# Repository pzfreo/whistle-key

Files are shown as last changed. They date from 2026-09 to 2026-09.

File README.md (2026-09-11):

# Burke whistle key attachment

A parametric build123d attachment for a brass high-D Burke whistle. The current
prototype extends the working single key to holes **4, 5 and 6**, with three
independent curved keys and springs. The latest trial uses **35° opening** and
**2 mm EVA liners glued straight to the keys**, with no separate TPU carrier;
see the [prototype and cutting-guide instructions](docs/eva-liner-prototype.md).

See the [three-key prototype](docs/three-key-prototype.md),
[assembly STEP](exports/three-key/assembly-open.step), and
[P1S PETG print project](exports/three-key/whistle-three-key-P1S.3mf), which is
a single all-PETG plate holding everything needed. A
[closed-position assembly STEP](exports/three-key/assembly-closed.step) shows
the pads seated on the whistle. Two 3 mm spring variants are also built:
[3 x 6 mm at 35 degrees](exports/three-key-3mm-spring/) and
[3 x 5 mm at 30 degrees](exports/three-key-3mm-short-spring/); see the
[three-key prototype notes](docs/three-key-prototype.md) for the trade. The new source is [scripts/three_key.py](scripts/three_key.py).

The earlier single-key prototype is retained below for reference.

Start with the [design brief](docs/design-brief.md) for player needs, agreed
hardware, provisional dimensions, manufacturing decisions and trial criteria.
The [acceptance tests](docs/acceptance-tests.md) define engineering assertions
and the usability requirements that need physical trials.

## Single-key print projects

The [all-PETG dry-fit 3MF](exports/single-key/whistle-key-P1S-dry-fit-PETG.3mf)
contains all six pieces on one plate for the P1S, including a rigid pad.
See the [printing notes](docs/printing.md) for orientations, settings and the
separate PETG/TPU version. Open as a project and slice in Bambu Studio.

## Single-key prototype

Edit the parameter block in [scripts/single_key.py](scripts/single_key.py).
Regenerate through the build123d MCP `execute_file` tool, then validate and
export the changed parts. Geometry uses millimetres.

- PETG frame, lever and two identical clamp caps; separate 95A TPU sealing pad.
- Fixed seats for a nominal 2 × 5 mm compression spring, assumed 2 mm solid.
- A 1 × 12 mm steel dowel, friction held in the fixed supports.
- Four M2 bolts and nuts; revised clamps sized for direct contact with brass.
- Low side hinge, curved arm around the tube, reinforced cheeks and a tested
  opening stop; glue-in pad retaining ring and small pin-fit coupon.

The [assembly STEP](exports/single-key/assembly-open.step) is for reviewing the
mechanism. Use the separate files in
[print-oriented](exports/single-key/print-oriented/) for slicing; print two
copies of `clamp_cap_print`. These files have orientations and bed placement,
but do not contain slicer settings or supports.

The [measured tube and hole 4 dimensions](docs/measurements.md) are now applied.
Hole 5 diameter and the remaining reference dimensions are still provisional.
The player confirmed the 1.0 mm pin bore. The first dry fit exposed weak
supports, an ineffective stop and finger obstruction; this curved-arm revision
addresses those findings and needs another physical trial. The player has assembled the spring and hinge and reports that the TPU makes
a reasonable seal. Grip and finger/key clearance failed that trial and are
addressed in the current revision; physical rechecking is still required. CAD validity and
sampled rigid movement checks passed; printability warnings and trial details
are recorded in the brief.

## Earlier layout study

[scripts/whistle_keys.py](scripts/whistle_keys.py), the top-level exports, and
`parameters.json` retain the earlier three-key study. They are not the active
single-key specification. `parameters.json` is an inventory, not model input.
Older concept images may predate manufacturing revisions.

## Build and test

Python 3.12 is used in CI. From the repository root:

```sh
python -m venv .venv
. .venv/bin/activate
python -m pip install -r requirements-dev.txt
python scripts/build_ci.py
python -m pytest -q
```

The headless build supplies the inspection helpers normally provided by MCP and
regenerates the active model into ignored `build/`. Tests check solid validity,
bed placement, clearances at 21 key positions, spring travel, pin fit geometry,
and STEP/STL round trips. They do not establish physical sealing or comfort.

[Build and test CAD](.github/workflows/cad.yml) runs on pushes, pull requests and
manual dispatch. Successful runs publish regenerated CAD files and a geometry
report as a downloadable `whistle-cad` artifact. Both the single-key and current
three-key prototypes are regenerated and tested.

## Titanium machining drawing

The [Draftwright drawing package](drawings/titanium/README.md) contains a
[two-sheet PDF](drawings/titanium/frame-machining-review.pdf), dimensioned DXFs,
a datum-aligned STEP and the Python regeneration script. It is for machining
quotation/review; material grade, metal pin retention and final instrument
measurements must be resolved before cutting.

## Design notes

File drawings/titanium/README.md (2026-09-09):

# Titanium frame — machining review P1

This package describes the existing three-key lower frame for a CNC machining
quotation and design-for-manufacture review. It is **not released for cutting**.
The titanium grade, metal hinge-pin retention, cutter access/internal radii,
and the player's hole 5/6 measurements remain unresolved. No supplier has been
contacted and no machining order has been placed.

The frame is a 3D milled/drilled component, not a flat laser/waterjet profile.
Its nominal envelope is **31.300 × 71.595 × 15.300 mm**. The 3.5 mm base is only
one level; raised bearings and spring housings are integral. Stock allowance
and workholding must be chosen by the machinist.

## Package

- `frame-machining-review.pdf`: combined two-sheet PDF for sharing.
- `frame-general.pdf`: orthographic/isometric views, envelope dimensions,
  proposed machining notes and release holds.
- `frame-features.pdf`: coordinate schedule, hole callout and functional sizes.
- Matching SVG and DXF files are drawing sheets, **not cutting toolpaths**.
- `frame-reference.step`: exact nominal geometry for CAM review. No titanium
  redesign or tool-radius compensation has been applied.
- `drawing-checks.json`: version/hash provenance and Draftwright diagnostics.
- `../../scripts/draw_titanium_frame.py`: reproducible Draftwright Python source.

The STEP is the committed PETG frame translated into a machining coordinate
system: X=0 is the whistle centreline, Y=0 the foot-end clamp centre and Z=0 the
flat underside. +Y points towards the mouthpiece; +Z towards the whistle.
Relative to `frame_print.step`, the translation is (0, 32.2975, 0) mm. Its shape
and volume are unchanged. Dimensions are in millimetres; do not scale a drawing.
Use the STEP for unlisted contours, with the drawing's fit notes and release
holds. Coordinate locations are nominal, not a claim that the instrument has
been measured to three decimal places.

## Manufacturing decisions to resolve

1. **Pin retention.** The 1.10 mm fixed bores were a PETG print-fit experiment.
   A machined 1.10 mm bore and 1.00 mm pin have 0.10 mm diametral clearance.
   Do not call this a press/friction fit. Agree bore limits and retention using
   the actual pins before revising the CAD. Preserve access for pin insertion.
2. **Nut pockets and internal corners.** The six 4.30 mm AF hex pockets have
   sharp nominal corners. Ordinary end milling leaves internal radii; the
   shop must propose corner relief or a suitable secondary process. Relief
   must preserve the nut-bearing flats, 1.6 mm roof and surrounding wall.
   This follows [Protolabs' CNC milling guidance](https://www.protolabs.com/services/cnc-machining/cnc-milling/design-guidelines/).
   Other sharp internal intersections also need cutter-access review; no blanket
   permission to add radii in moving-key clearances is given.
3. **Small cross holes and blind seats.** Six coaxial bearing bores run along Y.
   Three 2.4 mm spring sockets run along X and require a flat floor at full
   specified depth. A standard drill-point depth is not interchangeable with
   the 1.5 mm cylindrical spring seat. Inspect access and fixturing from both
   sides, underside and above.
4. **Whistle fit.** Three R7.15 seats share an axis. The 14.2 mm brass whistle,
   existing PETG caps and 1.2 mm nominal split gap are the starting interfaces.
   A geometric tightening allowance alone does not establish titanium clamp
   grip or acceptable pressure on the brass. Trial the metal assembly.
5. **Measurements and material.** Key 5/6 dimensions are being rechecked.
   Confirm these before fixing pedestal positions. Titanium grade and condition
   are not assumed. Tolerances and surface finish on the drawing are proposals
   for review, not measured or supplier-approved capability.

## Regeneration

Use a separate environment: the CAD project's tests use build123d 0.11.0,
whereas the inspected Draftwright version requires build123d below 0.11.

```sh
python -m venv /tmp/whistle-drawing-venv
/tmp/whistle-drawing-venv/bin/pip install -r drawings/titanium/requirements.txt
/tmp/whistle-drawing-venv/bin/python scripts/draw_titanium_frame.py
```

After changing the model, regenerate and datum-align the STEP through build123d
MCP before running the drawing script. The script reads the model parameter
block, checks the source STEP and emits the views through Draftwright. Review
both the machine-readable lint and the rendered PDFs; a clean drawing-layout
report would not release the part for manufacture.

## Drawing review and limitations

The fully automatic first pass reported dropped bore callouts and was stopped
after repeated layout retries. The refined version explicitly declares separate
bolt, spring and hinge hole groups and uses a coordinate table. This avoids
conflating the six vertical 2.4 mm bolt holes with the three horizontal 2.4 mm
blind spring sockets. It also adds a clamp section and shorter title-block text.

Visual inspection exposed two section-renderer issues in the pinned Draftwright
revision: rear-facing surfaces behind the section plane were hatched, and the
cut indicators pointed opposite the rendered +Y viewing direction. The drawing
script contains a narrowly scoped workaround: hatch only faces lying on the
specified cutting plane, and orient the indicators into the retained half.
It records hatch-face areas and excluded uncut faces for inspection. No manual
page coordinates are used to relocate views or dimension labels.

Draftwright still reports unsupported hex-pocket grammar and incomplete or
unverifiable feature provenance. Those warnings are retained in the JSON files;
the package does not claim automatic completeness. The coordinate and feature
notes supplement the views, and the STEP carries the remaining contours.
Independent assertions check actual cylindrical surfaces (counts, centres,
axes and depths), all 36 nut-pocket walls, and preservation of the original
frame geometry under translation. These are geometry checks, not validation
of metal friction fits, stiffness or manufacturing capability.

## Status update — 2026-09-09

The player has confirmed the recorded hole measurements. The measurement hold
on the archived P1 sheets is resolved. All three keys/pads now share the hole-5
size; this changes no frame geometry or hole coordinates. The P1 PDFs and trial
report are retained as issued. Material, metal pin retention and machining
intent still need resolution before a manufacturing release.

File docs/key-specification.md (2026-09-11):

# Burke whistle assistive key specification

This document is the restart specification for the three-key prototype. It
records the measured instrument, the agreed mechanical interfaces, and the
current experimental choices. It is intended to be sufficient to rebuild the
design in a new CAD session. All dimensions are millimetres unless stated
otherwise. The parametric implementation is `scripts/three_key.py`.

## Purpose and scope

The attachment adds normally-open keys to holes 4, 5 and 6 of a cylindrical
brass Burke high-D tin whistle. The keys let the player close a hole with a
deliberate press while reducing accidental muffling from a resting right-hand
index or middle finger. The key must return positively to an open stop when the
finger is released.

This is an assistive prototype, not a finished musical-instrument mechanism.
Tone, intonation, airtightness, fatigue life, spring force and comfort require
physical trials. CAD clearances are nominal and do not account for printer
tolerance, glue, foam hardness or spring-rate variation.

## Instrument datum and measured holes

Use the open foot of the whistle as axial datum zero. The whistle is cylindrical
at the attachment and has 14.2 OD. Hole positions are measured independently
from the foot; do not reconstruct them by adding adjacent gaps.

| Hole | Bottom edge | Axial diameter | Derived centre | Derived top edge |
|---|---:|---:|---:|---:|
| 3 (reference) | 100.00 | 5.80 | 102.90 | 105.80 |
| 4 | 79.15 | 5.09 | 81.695 | 84.24 |
| 5 | 62.05 | 7.80 | 65.950 | 69.85 |
| 6 | 35.30 | 7.60 | 39.100 | 42.90 |

The hole 4 transverse reading is 5.09. Transverse dimensions of holes 5 and 6
are not confirmed. Until they are measured, the model uses circular envelopes
from the axial readings as conservative clearance references, not as an
acoustic model. The direct gap checks were: hole 3 bottom to hole 4 top 15.60,
hole 4 bottom to hole 5 top 9.22, hole 5 bottom to hole 6 top 19.20, and hole 4
bottom to hole 6 top 36.30.

## Key layout

There are three identical interchangeable keys. They are intentionally sized
for the largest measured hole and are not engraved or position-specific.

- Common pad/contact diameter: 12.30.
- Key pad face outside diameter: 14.20 nominal, matching the whistle OD
  envelope. Minimum axial clearance between adjacent pads is 1.545.
- The pad face is integral with the key: a dished boss on the key underside,
  cut by a cylinder of 8.90 radius concentric with the whistle at closure
  (7.10 tube radius, less 0.20 interference, plus the 2.0 sheet).
- The glue surface is one continuous cylindrical face of 175.69, with no
  retaining ring, tab notch, step or parting line on it.
- Solid PETG above the dish: 3.80.
- The separate TPU carrier, its retaining ring and the pad locating tabs are
  superseded, as is the earlier widened carrier flare.

The key is a curved arm around the whistle, with a 4.0-wide hinge region, 3.0
thickness, 3.5 rear tail extension, and a widened 6.0 upper load path. The
upper arm has 1.0 extra radial stock and a 0.8 transition radius. A continuous
rear/tangent web fills the former weak notch. The hinge pivot axis is parallel
to the whistle axis, at X = -11.2 and Z = 0 in the local section coordinates;
the derived arm radius is 11.2. The pivot pin is 1.0 diameter.

The nominal open angle is 35°. Rotation is toward the open stop. At that stop,
the calculated pad-centre lift is 4.670 and the current uncompressed EVA
surface is about 4.163 from the reference tube. The angle was increased from
the earlier 20°/30° trials to keep the pad away from the airway. Forty degrees
was rejected for the current spring geometry because it leaves almost no
compression reserve.

## Pad and seal

The current pad system has one part: a single piece of 2.0-thick EVA sheet
glued into the dished face of the key. There is no separate carrier and no
second EVA layer. The nominal model uses 0.20 compression allowance at closure;
this is a trial assumption, not a measured foam property.
The EVA cutting guide is approximately 14.59 × 14.20 and is unrolled at the
mid-thickness radius. Trace and cut one liner first, curve it into the key's
dished face, check the edge, then glue it with a thin even layer suitable for
the actual PETG
and EVA. Do not cut a central hole in the liner.

The pad is intended to seal around each hole while leaving the hole itself
open when the key is raised. The CAD sealing-band check probes the current
face around each hole; physical leak and tone tests are mandatory. The open
pad must not intrude into the immediate airway. A changed pad outline or liner
thickness requires rerunning the sealing, airway and travel tests.

## Hinge, pin and spring

Each key has one friction-held steel dowel and one sideways compression spring.

- Pin: 1.0 × 12.0 steel dowel.
- Fixed bearing bores: 1.10 nominal diameter, with 0.25 lead-in allowance.
- Moving key bore: 1.25 nominal diameter.
- Fixed bearing crown radius: 3.0; minimum continuous collar wall: 0.90.
- Bearing ears are 3.2 axial thickness, leaving about 0.5 pin projection at
  each end. Pin insertion is from the foot end, in order 4, then 5, then 6.
- Spring: nominal 2.0 OD × 5.0 free length compression coil. Solid height is
  assumed 2.0; wire is nominally 0.3. The spring rate is unknown and must not
  be inferred from these dimensions.
- Closed spring seat spacing: 2.80. Current open spacing: about 4.624, leaving
  about 0.376 nominal compression at 35°.
- Spring socket diameter: 2.4, socket depth 1.5. Moving peg is 1.2 at its
  base, tapering to 1.0 at a 1.5-long tip.
- Spring seats are at Z = 3.1 in the current design. An 0.8 bevel at the upper
  rear holder corner clears the key's pad boss during travel.

The ordered 3.0 × 5.0 springs are not part of this revision. If a spring is
changed, check both solid-height margin and positive return before changing
the opening angle.

## Frame, clamps and fasteners

The frame is a PETG printed structure with three split clamps, three reinforced
hinge pedestals, a continuous low spine and an opposite-side 5.0-wide return
rail. Clamp centres are 28.10, 52.475 and 92.695 from the foot. The middle
clamp sits between holes 5 and 6. End clamp bands are 4.0 wide; bolt supports
are 6.0 wide. The nominal clamp inner radius is 7.15 (14.3 diameter seat for
the bare 14.2 whistle), with 0.05 radial clearance and a 1.2 split gap.

Use the matching printed caps. The frame and caps have underside hex pockets:
4.30 across flats, 1.90 deep, for nominal M2 nuts 4.00 across flats × 1.60
thick. Pocket clearance and actual nut dimensions need a physical fit check.
M2 bolt head envelope is 2.4 diameter × 2.0 high. The user's M2 bolts and nuts
are the intended hardware; exact bolt length remains to be confirmed.

The clamp faces must grip the bare whistle without a liner. A CAD closure check
shows the seat contacts before the faces bottom, but it does not establish grip
force. Tighten only enough to prevent movement and inspect the brass for marks.
The rail, clamp and hinge geometry must preserve finger access, especially over
the hole above the keyed hole.

## Materials and printing

- Frame, keys, caps and EVA cutting guide: PETG. Every printed part is PETG.
- Pads: 2.0 EVA foam sheet, cut from the supplied guide; not printed.
- Pins: friction-fit 1.0 × 12 steel dowels.
- Springs: nominal 2 × 5 compression coils.
- Adhesive: compatible with the selected PETG and EVA; thin glue layer.

Use the supplied P1S 3MF orientations. The frame and keys are printed with
their specified supports; the cutting guide is flat-base-down and
support-free. Print three identical keys. The single-plate 3MF holds the same
PETG parts as the two-plate project.

## Acceptance requirements

Automated CAD checks should verify:

- all three independent hole positions and common interchangeable geometry;
- valid closed solids and STEP/STL round trips;
- 21 sampled positions through the full 35° travel;
- key, pad, frame, tube and cap collision clearance;
- actual opening-stop contact and overtravel interception;
- open airway clearance;
- spring solid-height and preload margins, plus hinge/collar clearance;
- pin insertion path and bearing fit;
- sealing coverage around all three holes;
- pad tabs, ring notches and full pad seating;
- clamp, bolt-head and M2 nut-pocket geometry.

Physical trials remain required for print strength, pin insertion effort, spring
return, opening/closing force, clamp grip, EVA adhesion, airtight sealing,
finger clearance, fatigue and sound. Specifically compare each open note with
the unkeyed whistle; the 35° CAD clearance is not proof that the pad has no
acoustic effect.

## Restart checklist

Start from `scripts/three_key.py`, set the measured hole table and 14.2 tube
OD, then rebuild through the build123d MCP workflow. Regenerate the three-key
build and both 3MF projects, run `tests/test_three_key.py` and
`tests/test_package_3mf.py`, validate the printable parts, and inspect the
assembly STEP. Do not silently reuse older 20° or widened-carrier exports.

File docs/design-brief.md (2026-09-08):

# Burke whistle key attachment — design brief

Status: single-key development prototype, not yet fitted or played.
Updated: 7 September 2026.
Active parametric model: [`scripts/single_key.py`](../scripts/single_key.py).

## Purpose and player needs

Develop a removable key attachment for an existing brass Burke high-D tin
whistle. The player has Parkinson's disease and finds deliberate movements
against resistance easier to control than very light movements. The right index
finger, and to some extent the middle finger, can rest too close to a tone hole
and muffle notes even when that hole should be open.

The attachment should hold each affected hole positively open until the player
intentionally presses its key. The player should be able to rest a finger on the
contact without inadvertently shading the hole or partly closing the pad.
Required resistance and comfortable travel will be established by playing
trials, separately for each finger. Improvement in control is a design objective,
not a demonstrated result.

## Scope and agreed decisions

The eventual attachment covers holes 4, 5 and 6, numbered from the mouthpiece,
using three independent, normally open keys. The immediate prototype covers
only hole 4, operated by the right index finger. Validate this key before
extending the design to all three.

- Retain the existing instrument; use removable, lined split clamps.
- Use a printed supporting frame and a separate hinged finger lever.
- Use compression coil springs with fixed seats. Change resistance by replacing
  the spring, not by adding spring adjustment screws or torsion springs.
- Use a purchased 1 mm diameter × 12 mm steel dowel as the pivot. Hold it by
  friction in the fixed supports; provide running clearance in the moving key.
- Use the player's available M2 bolts and nuts for the clamp halves.
- Prototype a custom 95A TPU pad with a continuous curved sealing face.
- Print rigid parts in PETG on a Bambu Lab P1S; print the TPU separately.
- Keep dimensions in millimetres and geometry parametric in build123d.

## Mechanical layout

Two split clamps, immediately above and below hole 4, carry a short side rail.
The rail carries two pivot supports, spring seat and a fixed opening stop.
A curved lever wraps around the tube from a low side hinge, whose axis runs
parallel to the whistle at tube-centre height. Its round upper contact accepts the finger; the pad beneath closes
against the outside of the brass tube.

The spring pushes the lever open against a fixed stop. Some compression remains
at the open position to provide positive return. Deliberate finger pressure
closes the key against the spring. The TPU pad against the brass sets the closed
position; there is no separate rigid closing stop. Spring force at the finger depends on the lever
geometry as well as the unknown spring rate.

The prototype retains two clamps for mounting stability. Check that their
position leaves room for the other fingers and does not obstruct adjacent holes.
The CAD reference tube is only a lower tube segment, not a complete acoustic
model of a whistle.

## Pad and seal

The current trial pad is a separate TPU insert with a flat backing and a concave
cylindrical face matching the nominal outside of the tube, with 0.2 mm radial
interference for trial compression. The contact face is continuous across the
centre: the earlier annular lip and central relief have been removed at the
player’s request. The opposite backing is plain and flat.

A shallow retaining ring on the rigid key forms a flat-bottomed pad cup. Glue
the pad into this ring, aligning its curved face with the whistle before the
glue sets. The ring is 1.2 mm deep, with 0.8 mm walls and 0.3 mm total diametral
clearance around the pad. The TPU projects beyond the rigid rim so it contacts
the brass first. There is no central peg or recess in the pad backing.

The player will trial available 95A TPU first. Its firmness, printed texture,
seams and inaccurate alignment may cause leaks. The current dimensions are experimental; CAD validity does not prove
airtightness. Retain the option of a soft silicone sealing layer if printed TPU
cannot seal reliably at a comfortable force.

## Dimensions and assumptions

The player has supplied the [tube and hole 4 measurements](measurements.md).
Remaining unmeasured reference dimensions retain provisional high-D values.

| Item | Current value | Basis/status |
|---|---:|---|
| Tube outside diameter | 14.2 mm | Measured; cylindrical tube confirmed |
| Tube wall | 0.396875 mm | Provisional; bore derived from OD and wall |
| Hole 4 centre from open foot | 81.68 mm | Measured |
| Hole 5 / 6 centres from foot | 65.68 / 43 mm | Hole 5 derived from measured 16 mm spacing; hole 6 provisional |
| Hole 4 / 5 / 6 diameters | 5.09 / 6 / 5 mm | Hole 4 measured circular; holes 5/6 provisional |
| Single-key frame length | 26 mm | Upper clamp moved inward for finger clearance |
| Clamp width, each | 4 mm raised band; 6 mm bolt supports | Clearance revision |
| Nominal split gap | 1.2 mm | Bare-tube seat contact before bottoming checked |
| Liner allowance, radial | 0 mm | Direct brass contact; 0.05 mm radial seat clearance |
| Finger contact diameter | 11.49 mm | Widened to support retaining-ring wall |
| Pad-centre opening movement | 3.25 mm at 20° | Curved arm moves pad sideways as well as upwards; acoustic/comfort trial required |
| Pivot pin | 1 × 12 mm | User-identified steel dowel |
| Support / moving-key bore | 1.1 / 1.25 mm | Current printed-fit trial |
| M2 screw clearance | 2.4 mm | Prototype choice |
| TPU pad outside diameter | 9.59 mm | Derived from measured hole plus trial sealing margins |
| Nominal pad/tube radial interference closed | 0.2 mm | Intended elastic compression, not rigid clearance |
| Pad retaining ring | 9.89 mm ID, 11.49 mm OD, 1.2 mm deep | 0.3 mm diametral pad clearance |
| Compression spring OD / free length | 2 / 5 mm | User-found spring; treated as OD and free length |
| Spring solid length | 2 mm | Explicit user assumption, not supplier data |
| Spring rate | Unknown | Establish suitability by physical trial |
| Closed / open spring seat spacing | About 2.80 / 3.70 mm | Calculated from current geometry |

The spring has about 0.80 mm clearance above its assumed solid length at the
nominal modelled closure. Actual pad compression depends on finger force; this
is not a hard limit enforced by a rigid stop.
Its actual safe working stroke and force are unverified. The model shows a
cylindrical spring envelope, not a simulated coil; check retention and rubbing
as the moving seat tilts.

The spring is located in a 2.4 mm diameter fixed sideways socket, initially 1.5 mm deep,
and by a peg on the curved arm, 1.5 mm long with a 1.2 mm base tapering to a 1.0 mm tip.
The user's 0.3 mm wire gives a nominal 1.4 mm spring bore. The raised socket wall
provides retention without reducing initial preload. Increasing
`spring_floor_extra_depth` deepens only the floor towards the tube and reduces compression;
currently it is zero. Open preload displacement is about 1.30 mm, so available
floor-depth adjustment is limited. Retention and rubbing still need a trial.
The old `spring-socket-section.png` shows the superseded upright layout; turn count was illustrative.

The clamp split gap alone does not guarantee gripping force. The current
14.3 mm seat is sized for direct contact with the measured 14.2 mm tube, with
no liner. A geometric closure test establishes seat contact before the split
faces meet; real grip still depends on the printed fit and tightening. Tighten evenly and check both slipping and marking.

## Prototype bill of materials

| Component | Quantity | Material or specification |
|---|---:|---|
| Frame | 1 | PETG |
| Lever | 1 | PETG |
| Identical upper clamp caps | 2 | PETG |
| Curved pad insert | 1 | 95A TPU |
| Pivot dowel | 1 | Steel, 1 × 12 mm |
| Return spring | 1 | Compression coil, nominal 2 × 5 mm |
| Clamp bolts | 4 | M2; 12 mm length proposed, confirm with actual nuts |
| Clamp nuts | 4 | M2 external nuts |
| Clamp lining | None | Current seats sized for bare brass |
| Pad attachment | As needed | Removable adhesive, type to be selected |

The hinge-fit coupon is an optional PETG test print, not an installed component.

## Manufacture and assembly

Manufacturing changes included in the model:

- The hinge has short 3 mm thick cheeks with 6 mm wide roots, replacing the
  tall posts that broke in the first trial. The moving hub is 4 mm long.
- The pad has a plain flat backing for printing; the retaining ring prints
  upwards on the inverted key.
- A sideways spring housing keeps the spring below the playing surface.
- A broad angled opening stop meets the rear tail at 20°, verified by contact
  and overtravel tests. Physical strength and wear remain trial requirements.
- Independent STEP/STL copies are oriented and placed at bed height.
- A small coupon tests horizontal 0.9, 1.0, 1.1 and 1.25 mm bores. With its
  clipped base corner at lower left when viewed from above, sizes increase from
  left to right. Use the same PETG/profile as the frame and trial the actual pin.

| Part | Recommended orientation |
|---|---|
| Frame | Outer rail side down; supports enabled |
| Upper clamp caps | Flat semicircular end down; tube axis vertical |
| Lever | Flat finger face down; curved arm up; supports enabled |
| TPU pad | Flat backing down; curved contact face up |
| Fit coupon | Flat base down, as exported |

For a presumed 0.4 mm nozzle, initial settings discussed were 0.16 mm layers and
four walls for PETG, and 0.12 mm layers with solid construction for TPU. These
are untested starting points, not a calibrated printer profile. Inspect the
slicer preview, especially the 1 mm bores, small frame features and TPU contact face.
Do not put support contacts on the sealing face. Keep the TPU dry and follow its
manufacturer's settings; use external feeding for ordinary 95A TPU.

Use the coupon to choose friction grip without forcing the pin into a fragile
support. The moving lever must rotate freely. Select `pivot_support_clearance`
from the print result; do not assume a nominal 1 mm printed hole grips a 1 mm
rod correctly. The short coupon does not reproduce every aspect of the full
hinge; verify the assembled hinge too.

## Verification and acceptance

See [engineering assertions and usability acceptance tests](acceptance-tests.md)
for the requirements, automated checks and physical trial criteria.

CAD checks performed include valid, watertight individual part solids, 21-position
key and pad clearance checks through the opening motion,
and a frame-to-tube interference check after adding gussets.

Automated printability analysis no longer reports the frame's flat cantilever
shelves after the gussets were added. It still flags small frame features and
thin regions, and a thin region in the TPU contact face. It also flags possible tip-over
for the lever and clamp cap despite their broad planar bed faces; these warnings
have not been cleared by a slicer or physical print. Review adhesion and use a
brim if needed. This is not a fully validated production design.

The assembly STEP is a multi-body study, not a single printable object. The
spring envelope can intersect its seats slightly. Soft-pad interference in the
closed position represents intended compression, not a simulated deformation.

Before a playing trial:

1. Tube OD, hole 4 size/position and hole 4–5 spacing are recorded. Confirm
   adjacent-hole diameter, any offset around the tube, and finger/clamp space.
2. Print the fit coupon and verify pin grip and running clearance.
3. Inspect and assemble the rigid parts, liner, spring and pad; verify spring
   retention, free movement and clearance above solid at full closure.
4. Confirm a repeatable seal at comfortable finger pressure, including low notes.
5. Compare the open-hole sound with the attachment removed, including while
   resting a finger on the key. The pad must not audibly shade the open hole.
6. Check deliberate closing, reliable return, fatigue, finger contact comfort,
   and resistance to slipping or marking the brass during normal playing.
7. Repeat opening/closing and check for pin migration, loose pads, wear and leaks.

Revise from those results before extending to holes 5 and 6. No target finger
force, service life or quantitative acoustic tolerance has yet been agreed.

## Repository map and references

- [`scripts/single_key.py`](../scripts/single_key.py): active parameter block and
  reproducible geometry. Edit this for the current prototype.
- [`exports/single-key/`](../exports/single-key/): assembled STEP and individual
  parts in assembly coordinates.
- [`exports/single-key/print-oriented/`](../exports/single-key/print-oriented/):
  oriented individual STEP/STL files, including the pin-fit coupon.
- [`scripts/whistle_keys.py`](../scripts/whistle_keys.py): earlier three-key
  layout study. Its spring and pivot specifications are superseded for the
  active single-key prototype.
- [`parameters.json`](../parameters.json): legacy three-key parameter inventory,
  not an input to either model.

The [Humphrey high-D information](https://humphreywhistles.github.io/) informed
provisional tube sizing; it does not establish Burke dimensions. The
[Triple Play recorder account](https://www.jefftk.com/p/triple-play-recorder)
provides a related retrofit example and observations about sealing pressure.
[Flexo's compression-spring catalogue](https://www.flexosprings.com/stock-springs/compression-springs)
was investigated earlier; the current prototype instead follows the user's
2 × 5 mm spring assumptions. For material handling, see
[Bambu's TPU 95A guidance](https://uk.store.bambulab.com/collections/all/products/tpu-95a-hf),
while using the actual filament manufacturer's settings for printing and drying.

## First dry-fit feedback and curved-arm revision

The player confirmed the 1.0 mm printed bore fits the purchased pin. The first
frame's supports broke too easily, the opening stop did not work, and the tall
hinge obstructed the finger reaching the hole. Those are failed physical
requirements, not resolved by the earlier CAD collision tests.

This revision lowers the hinge beside the shaft and curves the arm up to the
pad, following the flageolet arrangement suggested by the player. The fixed
frame now carries the lower clamp halves; the removable caps are above. The
1 × 12 mm dowel, M2 fasteners and glued concave pad are retained. The spring
now acts sideways. Its rate and the resulting finger force are still unknown.
Repeat the PETG dry fit to assess finger access, cheek strength and the stop
before evaluating the TPU seal. See `curved-key-layout.png` for an end view
with the clamp rings omitted to expose the mechanism.

## Pin insertion access revision

The clamp joint now sits 7 mm below the pivot axis. Its tabs and the connecting
rail are lowered together; the rail top is 7.4 mm below the pivot. The upper
caps consequently extend farther down beside the tube. An open throat lets
them lift straight off rather than requiring sliding from the whistle end. Wider inward tab connections
join the clamp arcs without changing the M2 bolt centres or 0.8 mm split gap.
The existing key, 1 mm fixed bores and 1 × 12 mm pin are unchanged.

A continuous cylindrical sweep checks the entire 12 mm pin insertion from
beyond the lower clamp through the hinge. An additional 0.1 mm radial approach
allowance clears the frame, caps and tube; nominal 4 mm diameter × 2 mm tall
M2 head envelopes also clear. Actual head dimensions and hand access need a
dry fit. The lower rail lengthens the bearing supports; their 3 mm cheeks and
6 mm roots are retained, but printed strength must be checked again.

Print the updated frame and both caps together; the previous caps do not fit
the lowered joint. Insert the pin from the foot end, along the path illustrated
in `pin-insertion.png`. This revision checks pin access, not spring installation.

## Full-width hinge pillar reinforcement

Both pillars now broaden to the full 7.4 mm rail width from 1.2 mm below the
pivot axis down into the rail. These solid 3 mm thick buttresses replace the
tapered lower stems, adding about 91 mm³ of material to the frame. The pin
bores, insertion corridor, key and caps are unchanged. CAD verifies clearance
and solid continuity; improved printed strength still needs a physical trial.
Only the frame needs reprinting relative to the lowered-joint revision.

## Joined clamp base and enlarged spring peg

The notches where each lower clamp arc meets its rectangular tabs are filled
with a continuous base across the clamp width. The liner recess is retained.
This joins the arc and rectangular sections directly, as requested, without
changing the split gap, bolt holes or pin approach.

The spring peg is enlarged to 1.2 mm at its base, 1.0 mm at its tip and 1.5 mm
long. Against the assumed 1.4 mm spring bore this leaves 0.2 mm diametral
clearance, reduced from 0.4 mm. The larger peg needs a printed fit trial; spring
force settings are unchanged. Reprint the frame and key for this revision;
reuse the current caps and pad.

## Rounded key-arm shoulder

The sharp inside shoulder above the spring housing now has a 0.8 mm concave
fillet across the full 4 mm arm width. This adds material into the corner and
replaces the abrupt change of direction with a tangent radius. The CAD radius
is controlled by `arm_transition_radius`; the housing clearance and movement
checks still apply. This is a local stress-concentration improvement, not a
measured strength rating. Only the key needs reprinting for this revision.
See `key-arm-transition.png`.

The next friction-fit trial uses 1.1 mm fixed hinge bores with the existing 1.0 × 12 mm steel pin. The moving key bore remains 1.25 mm. This supersedes the 1.0 mm frame bore for the next print; retention is not yet confirmed. Only the frame changes.

## Joined lower pillar gaps

The lower gaps between the two bearing pillars and spring-seat base are now
filled by a solid pedestal across the rail width. Its top lies 2.3 mm below
the pivot, giving the 2 mm radius moving hub 0.3 mm nominal clearance. The
rear tail region is relieved to 2.9 mm below the pivot to preserve opening
travel and stop contact. Approximately 122 mm³ is added to the frame. The
1.1 mm fixed bores are retained. Only the frame needs reprinting.

## Working prototype feedback: grip and playing clearance

The player successfully installed the spring and hinge, operated the key, and
reports a reasonable TPU seal. Three P1 failures remain from that trial: the
mouthpiece-side band obstructs the neighbouring finger, the foot-side band
catches the key, and the clamp bottoms out without gripping. No liner was used.
The previous design retained a 0.5 mm radial liner allowance; claiming that its
split gap assured tightening clearance for the bare tube was incorrect.

The current revision uses a 14.3 mm seat diameter, zero liner allowance and a
1.2 mm split gap. The central lower cradle is raised into contact range while
the bolt tabs remain below the pin insertion path. At 0.06 mm inward movement
of each half, the CAD seats intersect the reference tube (contact established),
the halves do not collide, and the nominal split gap remains 1.08 mm. This is
a contact-before-bottoming test, not a simulation of gripping force.

Raised upper bands narrow from 6 to 4 mm; bolt supports remain 6 mm wide. The
mouthpiece-side clamp moves from 13 to 11 mm above hole 4, retracting its raised
outer edge by 3 mm. The foot-side band gains 1 mm clearance to the key. The
21-position motion check now includes both caps and requires at least 1 mm
key/pad clearance to them. Hole 3 position and actual finger envelope remain
unmeasured, so comfort requires a playing trial.

Reprint the frame and both caps together; key, spring, pin and TPU pad are
reusable. Captive M2 nuts remain a lower-priority follow-up.

## Three-hole extension

The current development prototype is described in [three-key-prototype.md](three-key-prototype.md). It extends the working curved mechanism to holes 4–6 using the reconciled independent measurements, larger pads for holes 5/6, a continuous supporting spine and two end clamps. Single-key geometry and print files remain available separately.

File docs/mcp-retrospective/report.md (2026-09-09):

# Field report: assistive whistle-key CAD workflow, printability checks and a misleading tip-over result

## Outcome

build123d-mcp helped turn an assistive tin-whistle key mechanism into a parameterised, printable assembly through repeated physical prototypes. Its strongest contribution was keeping geometry available for execution, measurement, inspection and export while the design changed. The user reported that the assembled spring and hinge worked and that the TPU pad made a reasonable seal.

The important limitation was the gap between valid CAD and a usable manufactured part. Several problems were discovered by the user handling printed parts: weak frame transitions, finger interference, key/frame catching, inadequate clamp tightening clearance and an unsuitable print orientation after a design change. These are failures of our design and verification coverage; they are not evidence that the CAD server produced invalid geometry.

This report includes a retrospective experiment with `analyze_printability`. It correctly identifies the old clamp's unsupported surface, but reports a questionable tip-over error for the corrected clamp. That is the main new actionable finding. Other suggestions below link existing issues rather than claiming previously unreported omissions.

## Environment and evidence

Reported by the running server on 9 September 2026:

| Component | Version |
|---|---|
| build123d-mcp | 0.3.84 |
| build123d | 0.11.1 |
| build123d-drafting-helpers | 0.14.2 |
| bd_warehouse | 0.3.0 |
| augura | 0.1.7 |

Project: [pzfreo/whistle-key](https://github.com/pzfreo/whistle-key). The mechanism uses PETG structural parts, TPU pads, steel hinge pins, compression springs and M2 fasteners around a cylindrical brass whistle. Development progressed from one key to three interchangeable keys and pads.

Reproducible geometry:

- [Old print-oriented clamp STEP, cbce323](https://github.com/pzfreo/whistle-key/blob/cbce323/exports/three-key/print-oriented/clamp_cap_print.step).
- [Corrected print-oriented clamp STEP, d6b1df1](https://github.com/pzfreo/whistle-key/blob/d6b1df1/exports/three-key/print-oriented/clamp_cap_print.step).
- [Corrected clamp image](https://raw.githubusercontent.com/pzfreo/whistle-key/d6b1df1/docs/clamp-cap-flat-end.png).
- [Canonical generation source](https://github.com/pzfreo/whistle-key/blob/d6b1df1/scripts/three_key.py) and [project assertions](https://github.com/pzfreo/whistle-key/blob/d6b1df1/tests/test_three_key.py).
- [Captured analysis evidence](https://github.com/pzfreo/whistle-key/blob/main/docs/mcp-retrospective/printability-evidence.json).

The versions above describe the retrospective run, not necessarily every server used during the project's history.

## What worked well

**Source-backed iteration.** Executing the repository's Python source and retaining named geometry made repeated changes practical. Parameters for hole spacing, pad size, pin clearance and frame geometry could feed the same generation workflow. Keeping the repository source authoritative matters: a successful interactive experiment alone is not a reproducible deliverable. This experience supports [#443](https://github.com/pzfreo/build123d-mcp/issues/443).

**Numerical checks alongside visual inspection.** Measurements, validity checks and exports gave concrete evidence about the result of edits. Renders helped communicate changes, while STEP files let the user inspect assemblies and individual parts. Neither a convincing render nor a successful export establishes finger clearance, clamp grip or support-free printing.

**Independent verification of drawing geometry.** During a separate Draftwright evaluation, a true section through the titanium frame reference measured 101.67622552458513 mm² in the MCP session. That agreed with the corrected drawing hatch area, approximately 101.676225524572 mm², and helped distinguish the intended section from incorrectly included geometry. See [drawing checks](https://github.com/pzfreo/whistle-key/blob/76ccdc2/drawings/titanium/drawing-checks.json) and [Draftwright report #1529](https://github.com/pzfreo/draftwright/issues/1529). The drawing defects belong to Draftwright; build123d-mcp was useful as an independent checker.

**A platform for engineering assertions.** We authored checks for key travel, frame and clamp clearance, pad seating, interchangeability and the clamp's first-layer connectivity. These are project-specific assertions built on CAD operations, not requirements automatically inferred or certified by MCP. Physical testing remained necessary for force, grip, sealing and usability.

## What went badly: we skipped an available printability check

The old clamp had a 4 mm-wide curved band between 6 mm-wide fastening tabs. In its supplied print orientation, the tabs touched the bed but the curved band began 1 mm above it. Validity and assembly checks did not catch that manufacturing problem.

The correction shortened the bed-facing tab extensions so the band and tabs begin on the same plane. The resulting cap has a connected C-shaped first-layer footprint.

An important correction to the initial retrospective: **`analyze_printability` already exists. We did not invoke it before delivering the problematic clamp.** Running it afterwards with a `256 256 256` build volume and other parameters at their defaults produced:

| Finding | Old cap | Corrected cap |
|---|---|---|
| Overhang | Warning: 98.1 mm² flat ceiling, 13.1 mm span; location Z ≈ 1 mm | No overhang finding |
| Tip-over | Error; projected centre of mass outside reported footprint | Error; projected centre of mass outside reported footprint |

The overhang result is a clear success for the existing tool. Our workflow should have run it on the actual exported print orientation before delivery. Absence of an overhang finding is still not a guarantee that every printer and slicing configuration will succeed.

## New finding: corrected curved cap gets a questionable tip-over error

For the corrected cap the tool says:

```text
Centre of mass (-0.0, 0.8) projects outside the bed-contact footprint; the part will topple
```

The finding has `kind: tip_over`, `severity: error`, and null `area` and `location`.

We independently reconstructed the static support polygon from the bed-contact geometry. Bed faces were selected where both minimum and maximum Z were within 1e-6 mm of zero. A convex hull made using only topological vertices excludes the lower extrema of the curved edges. Sampling each contact edge at 33 parameter positions captures those curves:

| Measurement | Old cap | Corrected cap |
|---|---|---|
| Bed-contact faces | 2 | 1 |
| Projected centre of mass, Y | 1.27956 mm | 0.83773 mm |
| Vertex-only hull contains projected COM | No | No |
| Sampled contact hull Y extent | 4.775 to 8.275 mm | −8.275 to 8.275 mm |
| Sampled contact hull contains projected COM | No | Yes |

The corrected cap's projected centre of mass lies inside the convex hull of actual sampled contact points. A C-shaped footprint can support a centre of mass projected into its open region; static stability depends on the support polygon, not simply whether that point lies in contact material.

This contradicts the categorical geometric explanation for the corrected cap. A vertex-only hull or a footprint-membership test is a possible explanation, **not a confirmed implementation diagnosis**: we have not inspected the analyzer's source to establish the cause. This should be investigated in the MCP/augura analysis path.

No physical stability experiment was performed for this retrospective. Adhesion, nozzle forces and printing dynamics remain separate concerns even when the static support-polygon test passes.

### Reproduction

Download the two linked STEP files and execute in the MCP session:

```python
from build123d import *
old_cap = import_step('/absolute/path/cap-before.step')
new_cap = import_step('/absolute/path/clamp_cap_print.step')
show(old_cap, 'review_old_cap')
show(new_cap, 'review_new_cap')
```

Then call `analyze_printability` once per object:

```json
{"object_name":"review_old_cap","build_volume":"256 256 256"}
```

```json
{"object_name":"review_new_cap","build_volume":"256 256 256"}
```

For the independent check, collect the coplanar Z=0 faces, sample each edge with `edge.position_at(i / 32)` for `i` from 0 through 32, compute their 2D convex hull, and test `part.center(CenterOf.MASS)` projected into XY against that hull. The captured evidence includes both the vertex-only and sampled results.

## Other friction and opportunities

**Structured results and output size.** Some results put prose and serialised JSON inside a string, alongside text and structured wrappers. That creates extra parsing work and makes it easy to repeat large outputs. Our orchestration also amplified this by displaying entire response objects. Compact typed results with optional detail would help; relevant existing work is [#449](https://github.com/pzfreo/build123d-mcp/issues/449), [#370](https://github.com/pzfreo/build123d-mcp/issues/370) and [#437](https://github.com/pzfreo/build123d-mcp/issues/437).

**Optional capability discovery.** Server instructions advertised Draftwright as importable, but it was absent from the execution environment. We used a separate local environment for the drawing workflow. This is already tracked in [#475](https://github.com/pzfreo/build123d-mcp/issues/475); the desired improvement is accurate optional-package discovery and conditional guidance, not mandatory installation. Package/source introspection also encountered sandbox restrictions. A supported capability/version interface is preferable to weakening the sandbox.

**Actionable diagnostic evidence.** A tip-over finding should expose its assumed bed plane, contact region or hull, projected centre of mass and geometric margin. A render overlay would make a disagreement much easier to resolve. Related diagnostic-location concerns exist in [#436](https://github.com/pzfreo/build123d-mcp/issues/436), although that issue concerns thin walls rather than this support-polygon example.

**Separate validation results.** Workflow guidance should distinguish solid validity, assembly clearance, printability in the final orientation, and user-defined engineering requirements. A single successful validity result must not imply all four passed. Named object identity and the exact analyzed/exported orientation should remain explicit so checks apply to the delivered geometry.

## Suggested priorities and acceptance criteria

1. **Investigate the curved-contact tip-over result.** Add the corrected cap as a regression fixture. Include curved contact boundaries in the support calculation and report the actual geometric evidence. If another criterion triggers the error, explain it rather than asserting that the projected centre of mass lies outside its support polygon.
2. **Make existing printability analysis a routine delivery step.** Guidance should call it on print-oriented parts and review unresolved findings before export delivery. The old cap should retain its Z≈1 mm overhang warning; the corrected cap should not have that same warning. This is a workflow improvement, not a request for a new analyzer.
3. **Expose useful diagnostic geometry.** Return the support hull, projected centre of mass and assumptions in typed data, ideally with an optional annotated view. Avoid an unconditional prediction of toppling where the analysis is heuristic or incomplete.
4. **Continue existing capability and response-schema work.** Link this report as evidence for #475 and #449 rather than opening duplicate requests.

The overall assessment is positive: the server made iterative CAD and independent checks practical. Its value increases when available analysis tools are actually used, results identify their assumptions, and project-specific engineering requirements remain explicit. The physical prototypes exposed gaps that valid solids and attractive renders could not settle.

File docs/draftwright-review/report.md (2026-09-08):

# Field report: titanium-frame drawing — section correctness, hole semantics, documentation and iteration

Draftwright produced a useful two-sheet machining-review package from a real, moderately complex STEP model. Its domain-level authoring, repeated-hole callouts, automatic view placement and multi-format export were valuable. However, getting a trustworthy result required visual inspection, independent geometry checks, a private renderer workaround and several API corrections. The most serious problem was a section view that hatched uncut material. A separate lint suggestion would have incorrectly merged two distinct drilling operations.

This report records one practical trial, not a controlled performance benchmark or a claim that every issue affects every model. Suggested priorities below are for triage. It can serve as a parent issue for smaller fixes.

## Task, environment and evidence

The task was to create and improve a technical drawing for a titanium version of a three-key whistle frame. The input remained the nominal PETG prototype geometry: this exercise produced a quotation/design-for-manufacture review, not a released titanium design.

| Item | Trial configuration |
|---|---|
| Date | 2026-09-08 |
| Draftwright | `0.4.25.dev0`, source commit `c365452ac4603f7d86b3c45545ce6c312be4e16b` |
| Python/platform | Python 3.12, Linux x86-64 |
| Drawing environment | build123d `0.10.0`, build123d-drafting-helpers `0.15.1`, Quiddity `0.2.6`, cadquery-ocp `7.8.1.1.post1` |
| Existing CAD project | build123d `0.11.0`; ultimately kept in a separate environment |
| Model | One solid; 210 faces, 597 edges; 31.300 × 71.595 × 15.300 mm |
| Volume | 6313.313392 mm³ |
| Features | Six vertical bolt holes, six horizontal hinge bores, three horizontal blind spring sockets, six underside hex nut pockets, curved whistle seats and raised supports |
| Final output | Two A2 sheets at 2:1 for orthographic views; isometric views marked NTS; PDF, SVG, DXF, STEP and Python source |

Pinned trial artifacts:

- [Datum-aligned STEP](https://github.com/pzfreo/whistle-key/blob/76ccdc2/drawings/titanium/frame-reference.step)
- [Original print-frame STEP used by the automatic first pass](https://github.com/pzfreo/whistle-key/blob/76ccdc2/exports/three-key/print-oriented/frame_print.step)
- [Final Draftwright Python generator, including the workaround and independent checks](https://github.com/pzfreo/whistle-key/blob/76ccdc2/scripts/draw_titanium_frame.py)
- [Combined drawing PDF](https://github.com/pzfreo/whistle-key/blob/76ccdc2/drawings/titanium/frame-machining-review.pdf)
- [Machine-readable checks and lint](https://github.com/pzfreo/whistle-key/blob/76ccdc2/drawings/titanium/drawing-checks.json)
- [Dependency pin](https://github.com/pzfreo/whistle-key/blob/76ccdc2/drawings/titanium/requirements.txt)
- [Automatic-pass interruption log](https://github.com/pzfreo/whistle-key/blob/186c895/docs/draftwright-review/automatic-first-pass.log)

The final package is explicitly marked **QUOTATION / DFM REVIEW — NOT RELEASED**. Titanium grade, metal pin retention, internal-corner machining and final instrument measurements were not settled. Those are engineering inputs; Draftwright should not invent them.

## What went well

### 1. Useful views from the actual solid

Orthographic and isometric views made the frame understandable. The final layout also accommodated a clamp section, coordinate schedule and substantial machining notes. This was much better than manually tracing a raster image or reconstructing the shape as a drawing.

### 2. Domain-level authoring was a productive fallback

After the fully automatic approach struggled, `Sheet`, `envelope()`, `hole()`, `dimension()`, `table()` and `notes()` let us state the required information while leaving placement to the engine. We did not manually place the principal views or ordinary dimension labels.

The successful feature sheet separates:

- **6 × Ø2.4 through bolt holes**, axis Z;
- **3 × Ø2.4 blind spring sockets**, axis X, 1.5 mm full-diameter depth;
- **6 × Ø1.1 nominal hinge bores**, axis Y, with the metal fit explicitly on hold.

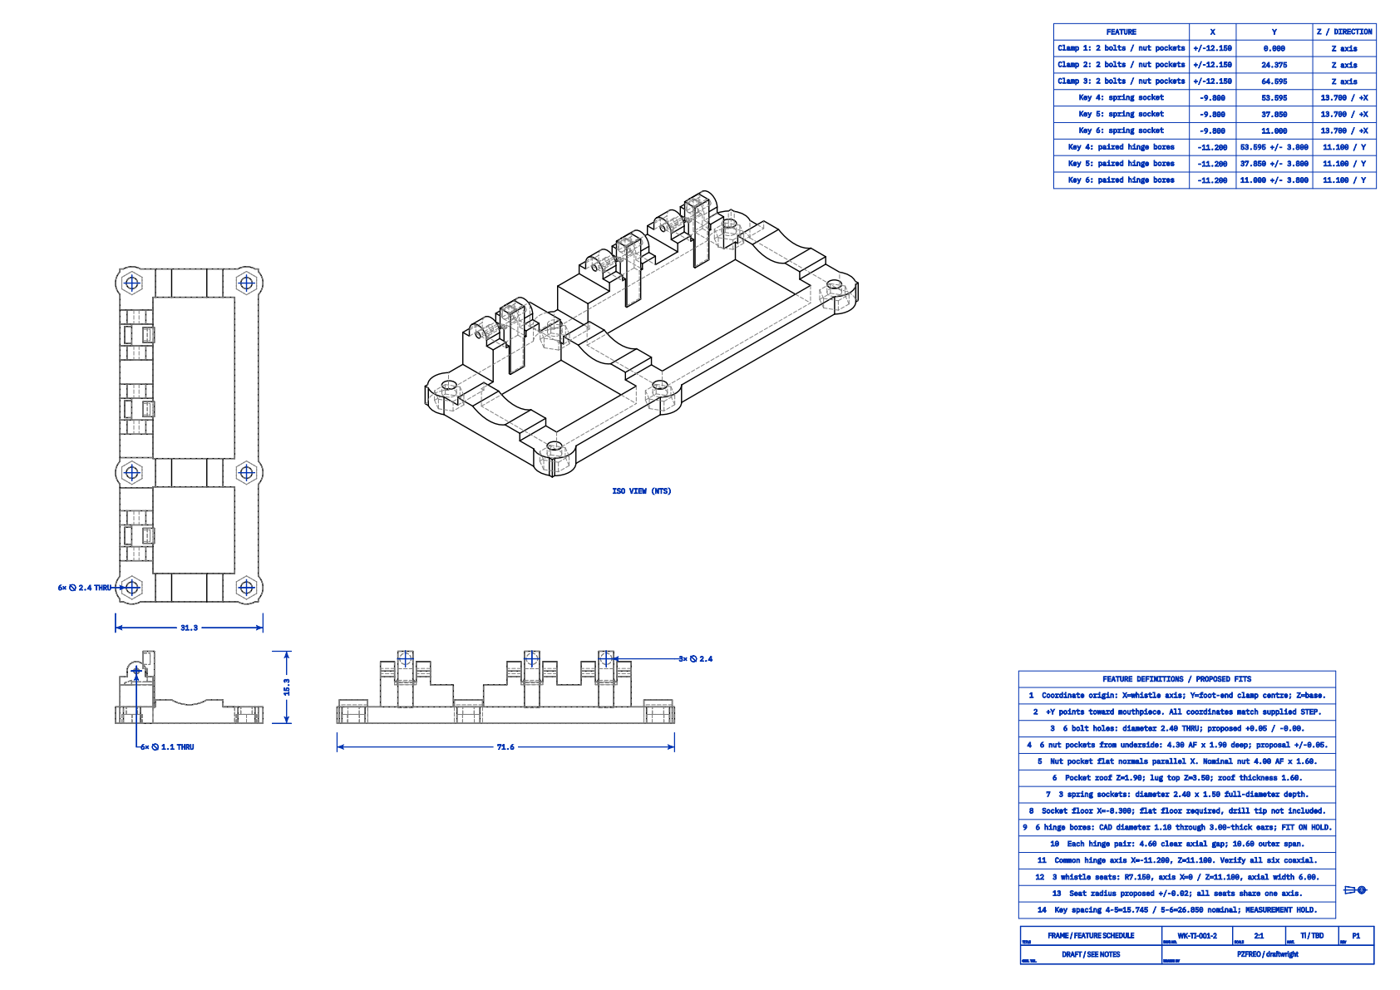
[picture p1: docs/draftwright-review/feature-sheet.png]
Final feature sheet


The coordinate schedule was particularly useful: this frame has repeated features along different axes, and placing every coordinate as a separate dimension would make the sheet harder to read.

### 3. Diagnostics exposed uncertainty

The reports retained unsupported and unverifiable requirements instead of treating them as fully covered. In particular, six hexagonal blind recesses were identified as unsupported by the current drafting grammar. The distinction between legibility, fidelity and completeness is useful, and the detailed reasons are worth preserving.

### 4. Export and reproducibility worked

PDF, SVG and DXF export all succeeded in the isolated drawing environment. It was practical to retain the generator, source STEP, version pins, hashes and diagnostics alongside the outputs. The final ZIP passed an integrity check and the combined PDF contained the intended two sheets.

### 5. The design-intent boundary remained explicit

The drawing could carry unresolved fits, material and machining notes without making up a titanium grade or claiming that a printed hole allowance was a metal press fit. That is the right outcome for this stage of the design.

## What went badly

### A. High priority: section hatching included material behind the cut plane

**Confirmed on the fixture, visually and by source inspection.**

We requested a section at Y=0 through the foot-end clamp. The generated section hatched raised hinge-support faces farther along Y, although those faces were not intersected by that plane. This changes what the drawing says about the part; it is not merely cosmetic.

The relevant selection in [sections.py at the tested revision](https://github.com/pzfreo/draftwright/blob/c365452ac4603f7d86b3c45545ce6c312be4e16b/src/draftwright/annotations/sections.py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) is:

```python
cut_faces = [f for f in keep_behind.faces() if f.normal_at().Y < -0.9]
```

That selects faces by orientation, without requiring them to lie on the cutting plane. Rear-facing surfaces on retained features therefore enter the hatch set.

**Before:** uncut supports are hatched.

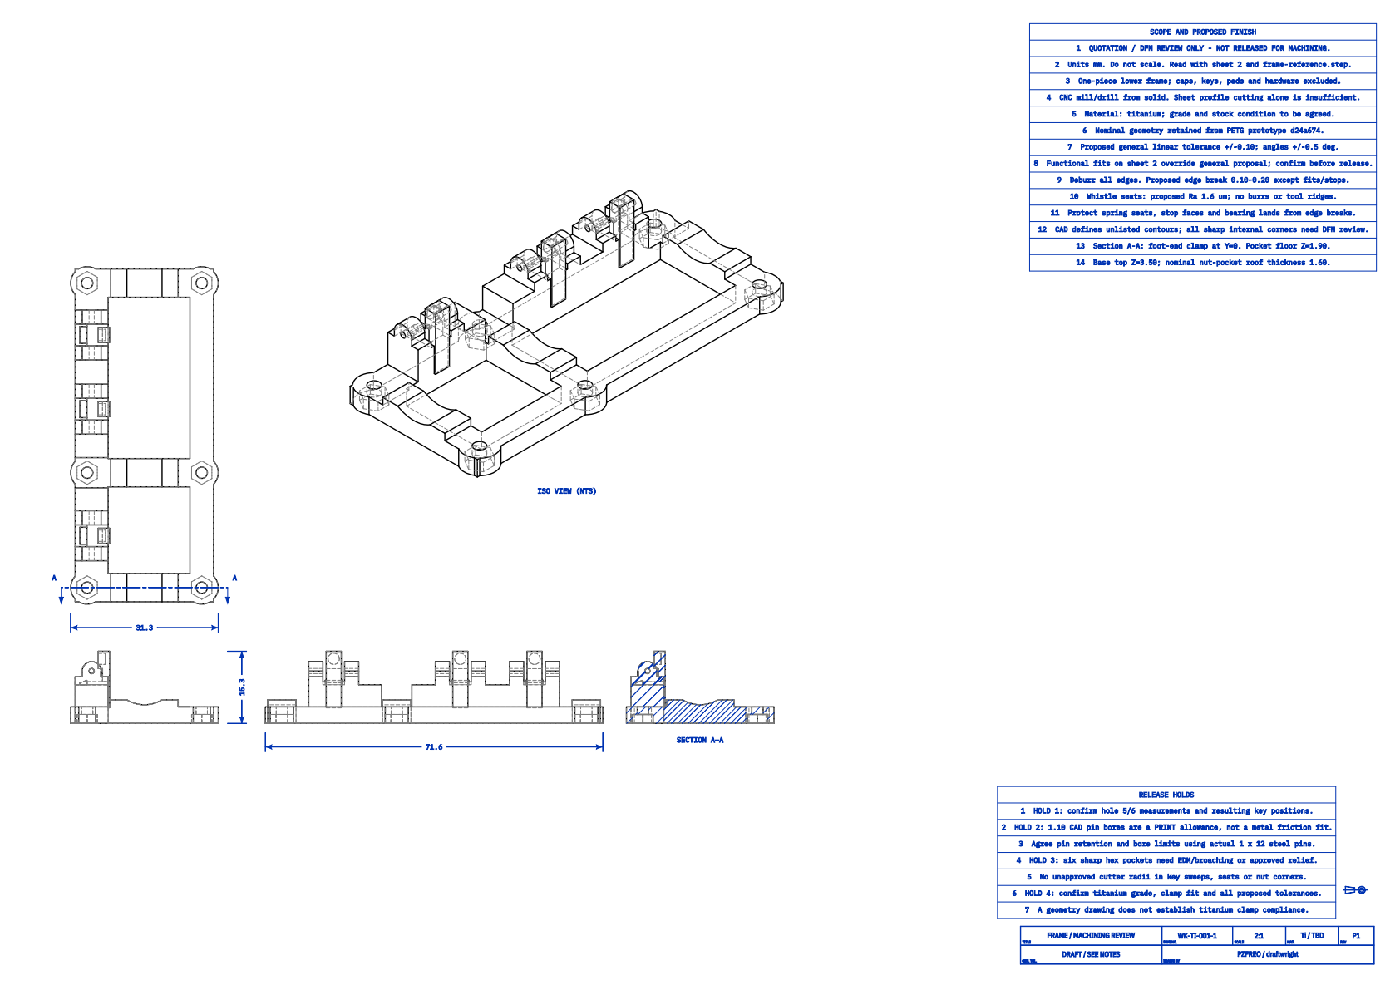
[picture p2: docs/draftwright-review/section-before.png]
Before section correction


**After the local correction:** only material intersected by Y=0 is hatched; retained features behind it remain visible but unhatched.

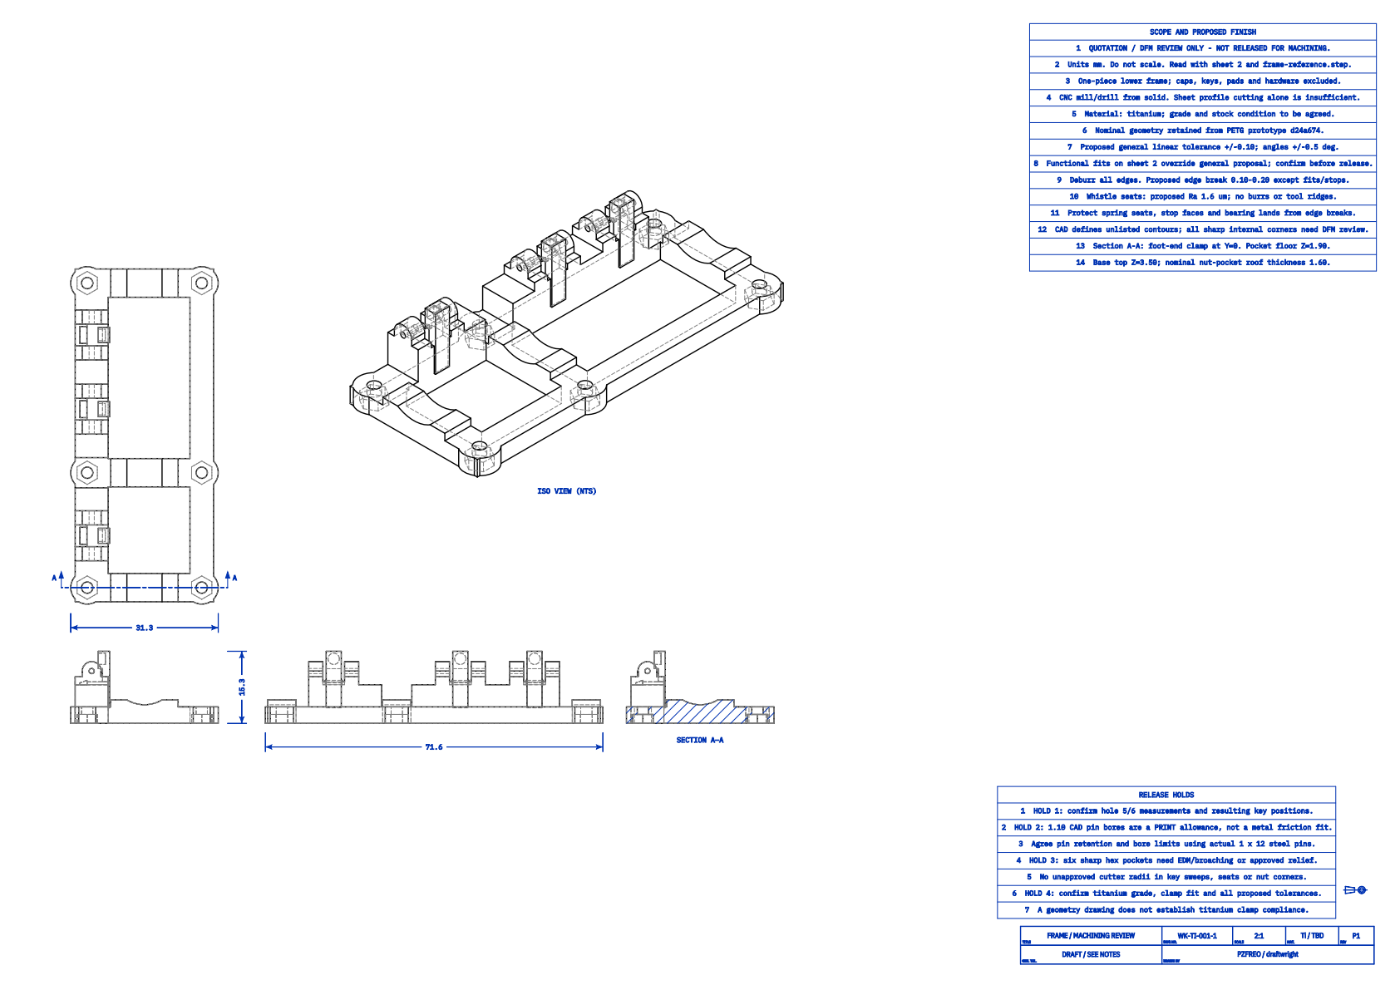
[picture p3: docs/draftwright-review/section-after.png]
After section correction


The bounded workaround filtered candidate hatch faces to those whose Y bounds both match the cut plane within tolerance. For this fixture it:

- excluded **17 uncut faces**;
- retained **3 actual cut faces**;
- produced total cut-face area **101.676225524572 mm²**;
- matched an independent build123d section, **101.676225524585 mm²**, within 1e-5 mm².

This workaround is evidence, not a proposed universal API or complete treatment of arbitrary section geometry. The upstream fix should use reliable cutting-plane/intersection provenance.

**Requested regression:** place raised rear-facing features behind, but not on, a section plane. Assert their faces are not hatched; compare the hatched region with the actual section region, including voids. Check more than screenshots and normal directions.

### B. High priority: section indicators opposed the rendered viewing direction

**Observed and supported by the renderer implementation for this fixture.**

The renderer removes the lower-Y half and places the camera at lower Y looking toward the retained positive-Y half. The plan-view indicators were constructed with `tip_y = y_page - wing_h` and `rotation=-90`, pointing in the opposite direction on this drawing.

The local correction points them into the retained half. Relevant source is [the section camera and arrow construction](https://github.com/pzfreo/draftwright/blob/c365452ac4603f7d86b3c45545ce6c312be4e16b/src/draftwright/annotations/sections.py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).

**Requested regression:** verify the section plane, removed half, retained half, camera direction and projected indicator vectors as one contract. Exercise first- and third-angle layouts, with an asymmetric part so a reversed view is observable. The local trial covered third angle only.

### C. High priority: a lint fix merged different operations solely because their diameters matched

**Observed in an intermediate feature-sheet diagnostic.**

With the six bolt holes declared, lint said:

```text
9 ø2.4 features on the part but callouts account for 6
```

Its suggested fix was to set the callout count to nine. But the other three features are blind spring sockets along X; the six bolt holes are through holes along Z. Changing the bolt callout to `9× Ø2.4 THRU` would be false.

We instead declared a separate three-socket group. The count warning then disappeared while retaining the two different operations. The diameter-only suggestion is also visible in [linting/suggest.py](https://github.com/pzfreo/draftwright/blob/c365452ac4603f7d86b3c45545ce6c312be4e16b/src/draftwright/linting/suggest.py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).

**Requested improvement:** preserve axis, through/blind status, depth and occurrence ownership in count reconciliation and suggestions. When diameters match but operations differ, identify the unclaimed occurrences and propose a separate group. Do not issue a mechanically applicable count change that alters manufacturing meaning.

### D. Medium priority: the automatic first pass was slow and opaque

The first pass used `build_drawing()` with A2, requested scale 2, third-angle projection and automatic dimensions. It repeatedly printed:

```text
plan/side right strip: 1 of 2 bore callouts skipped (strip full)
```

It ran for several minutes without delivering its first exported sheet and was interrupted. **This does not prove an infinite loop or establish a runtime benchmark.** We did not profile every stage, and other local work was running during part of the trial.

The interruption stack was in leader placement/materialization, specifically `_rendered_ink_matches()` → `_validated_face_mesh()` → edge enumeration. It would be inaccurate to attribute this incident solely to exact HLR.

**Requested improvements:** stage-level progress and elapsed times, candidate/scale retry reporting, a bounded search budget, and retention of the best diagnostic result on cancellation. Profile annotation ink materialization as well as projection. Related: #1137 and #1228, but this is not evidence of the same root cause as either.

### E. Medium priority: the skill and section API did not line up cleanly

The inspected skill teaches `Sheet.section()`. The implementation warns that it is deprecated and recommends `add_section_view()`/`section_view()`.

Trying `add_section_view('A', at=0)` on an explicitly authored sheet then failed with:

```text
augment automatic derived views; call auto_views() first
```

Adding `auto_views()` succeeded, but produced a soft-deprecation warning recommending `authored_views()` plus explicit view declarations. That warning is not a removal notice; nevertheless, the discovery path was unnecessarily circuitous.

There was also an operator error: `s.dimension(bolt, 'diameter')` failed because the Sheet measurement ID is `bore.diameter`. The exception helpfully listed valid measurements. The skill does explain that `Drawing.dimension()` and `Sheet.dimension()` use different spellings, so this is not wholly a documentation failure.

**Requested improvements:** test the skill's examples against the shipped package; include a complete current example combining authored dimensions with a section; demonstrate hole `bore.diameter` and `dimension_ids()` explicitly. This is related to the already-closed #988, with a different remaining section-workflow mismatch.

### F. Medium priority: completeness does not reconcile the two-sheet package and its notes well

Final recorded results:

| Metric | General sheet | Feature sheet |
|---|---:|---:|
| Errors | 0 | 0 |
| Warnings | 35 | 36 |
| `passed` | true | true |
| Overall `score` | 0.0 | 0.0 |
| Legibility score | 1.0 | 1.0 |
| Recognized requirements in audit | 58 | 58 |
| Requirements placed | 0 | 2 |
| Satisfied by structured note | 0 | 0 |
| Unsupported | 6 | 6 |
| Unverifiable | 52 | 47 |

The feature sheet additionally reported three suppressed requirements. We are not treating those as valid coverage simply because the drawing looked readable.

Some general-sheet warnings are expected: the drill information deliberately lives on sheet 2. The feature notes also state pocket AF/depth, socket depth, bearing spans and seat sizes, but ordinary free-text notes do not establish structured requirement ownership. It is reasonable not to infer semantic coverage from arbitrary prose.

The problem is the workflow gap: after doing the sensible human thing—split the information across sheets and use a feature schedule—the report still needs extensive manual interpretation. An extra `repair()` left both final summaries unchanged; it did not resolve this semantic gap, nor should we expect a layout repair to invent feature provenance.

**Requested improvements:** package-level requirement ownership, supported feature-linked schedules/notes, and a concise distinction between layout validity, geometry coverage, fidelity uncertainty and missing manufacturing decisions. `passed=true` beside a zero score and dozens of warnings needs an immediately visible explanation. Do not make the score greener by suppressing unsupported requirements.

The feature sheet also retained two `diameter_leader_target_unverifiable` warnings. We visually inspected the leaders and independently checked the bores, but that is not a complete automated proof of leader-to-boundary fidelity. Those warnings should remain actionable, with feature/view identity and a highlighted target preview.

### G. Lower priority: presentation and export needed polish

The initial long material field was crowded in the title block. Shortening it to `Ti / TBD` improved the output. It would be better for title-block fields to fit, wrap or report overflow explicitly.

The A2 pages were readable but left substantial unused space while the note blocks were relatively small. A layout preference for larger notes or a more compact sheet would help. This is an editorial observation, not proof that the optimizer chose the wrong feasible layout.

The final DXFs were approximately **8.55 MB and 8.74 MB**, with SVGs around **1.48 MB and 1.52 MB** and PDFs around **0.56 MB each**. Generated drawing files created extremely noisy repository diffs until marked as generated/binary for review. Compact export options and documented Git attributes would help; this trial did not isolate which entities dominate size.

## Environment problems: distinguish integration from our mistakes

The available CAD MCP server advertised Draftwright as importable, but `import draftwright` returned `ModuleNotFoundError`. We therefore ran Python locally against the verified STEP. This was an integration/deployment mismatch, not proof of a Draftwright import defect.

We initially installed Draftwright into the CAD project's existing virtual environment. That was our mistake. The declared dependency correctly selected build123d below 0.11, downgrading the project's version. Restoring build123d then exposed overlapping OCP distributions until the original OCP packages were restored. The successful approach was a separate drawing environment.

Suggested improvement: a short preflight that reports package presence, kernel/dependency compatibility and the intended execution environment before a CAD-to-drawing workflow starts. Document the isolated-environment route prominently while supported versions differ.

## Reproduction

For the full corrected package and independent checks:

```sh
git clone https://github.com/pzfreo/whistle-key.git
cd whistle-key
git checkout 76ccdc2
python -m venv /tmp/whistle-drawing-venv
/tmp/whistle-drawing-venv/bin/pip install -r drawings/titanium/requirements.txt
/tmp/whistle-drawing-venv/bin/python scripts/draw_titanium_frame.py --verify-only
/tmp/whistle-drawing-venv/bin/python scripts/draw_titanium_frame.py
```

A reduced fixture-based reproduction for the unpatched section renderer is below.
It uses the same section request and input as the observed failure, but omits the
notes and tables; this reduced snippet has not been separately run. The archived
before/after images and source inspection are the evidence from the actual run.

```python
from build123d import import_step
from draftwright import Sheet

part = import_step('drawings/titanium/frame-reference.step')
s = Sheet(part, title='CLAMP SECTION REPRO', number='REPRO-1',
          page='A2', scale=2, projection='third',
          tolerance='REVIEW ONLY', detail_view=False)
env = s.envelope(part)
for parameter_id in env.dimension_ids():
    s.dimension(env, parameter_id)
s.auto_views()
s.add_section_view('A', at=0.0)
d = s.build()  # No consumer-side corrected_section() patch.
d.export('build/section-repro', formats=('svg', 'pdf'))
```

The original automatic call, before the domain-authored fallback, was:

```python
from draftwright import build_drawing

d = build_drawing(
    'exports/three-key/print-oriented/frame_print.step',
    title='THREE-KEY FRAME - TITANIUM REVIEW',
    number='WK-TI-001', material='TITANIUM - GRADE TBD',
    tolerance='SEE REVIEW NOTES', page='A2', scale=2,
    projection='third', date='2026-09-08', revision='P1',
    reproducible=True,
)
```

The independent checks validated cylinder counts, centres, axes and depths; all 36 hex-pocket walls; preservation of original frame geometry under translation; and the corrected section area. These checks do **not** prove all dimensions are present, all leaders are faithful, or the design is ready to manufacture. The CAD repository's CI also passed, but it is not a Draftwright acceptance test.

## Suggested follow-up order and acceptance criteria

1. **Section correctness:** reproduce A/B, fix cut-face selection and indicator direction, and add geometric regression assertions before more layout polish.
2. **Safe count suggestions:** add this mixed-axis, mixed-depth Ø2.4 fixture; never suggest a false nine-through-hole operation.
3. **Public review workflow:** make feature provenance, unsupported geometry, retained warnings and package-level ownership straightforward to inspect. Build on the existing contracts in #1256 rather than introducing another parallel report model. Its current checkpoint already records delivered inspection/report work; this trial did not evaluate all of it.
4. **Skill/API consistency:** execute the documented examples in CI, including a section on an authored sheet, and keep migration advice consistent.
5. **Iteration cost:** instrument this fixture, separate recognition/projection/placement/ink-check/lint/export costs, and return bounded, useful results when automatic placement struggles.
6. **Shop-package usability:** improve title-block fitting, note legibility, artifact manifests and export size. Keep preliminary status distinct from manufacturing release.

The core approach worked: the final drawing communicated a difficult little frame well. The next improvement should make that result trustworthy through supported APIs and geometric evidence, without requiring a consumer to patch private section-rendering functions.

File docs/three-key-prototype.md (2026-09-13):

# Measured three-key prototype

The working hole-4 mechanism is extended to holes 4, 5 and 6 on one 71.595 mm
frame. Each curved key has its own normally open coil spring, 1 × 12 mm steel
pin and an integral concave pad face carrying a glued 2 mm EVA liner. All
three keys are now identical,
sized for the largest measured hole (7.80 mm). All geometry is metric and controlled
by `scripts/three_key.py`.

## Measurements and pad sizes

Bottom edges are independently measured from the whistle foot; centres are
derived separately from the axial diameters, as requested by the player.

| Hole | Bottom edge | Axial diameter | Centre | Pad OD | Cup OD |
|---|---:|---:|---:|---:|---:|
| 4 | 79.15 | 5.09 | 81.695 | 12.30 | 14.20 |
| 5 | 62.05 | 7.80 | 65.950 | 12.30 | 14.20 |
| 6 | 35.30 | 7.60 | 39.100 | 12.30 | 14.20 |

Centre spacings are 15.745 mm and 26.850 mm. Hole 3 is included as a reference
at centre 102.90 mm, diameter 5.80 mm. The unkeyed hole 3 bottom edge is 100 mm.

Transverse sizes of holes 5 and 6 are unconfirmed. The model uses circular
clearance envelopes with the measured axial diameters, conservatively covering
holes whose transverse dimensions do not exceed those values. These envelopes
are not a claim that the real holes are circular or an acoustic whistle model.
The player confirmed the recorded hole measurements on 2026-09-09. The common
pads require a sealing trial; only the earlier, smaller hole-4 TPU pad has been tried.

## Frame and clamps

End clamps sit at 28.100 and 92.695 mm from the foot, with a third clamp
between keys 5 and 6 at 52.475 mm. The raised bands are
4 mm wide and the bolt supports 6 mm wide. The upper band stops at 94.695 mm,
leaving 5.305 mm to hole 3's bottom edge. Actual finger comfort remains a trial.
A continuous low spine joins the three reinforced hinge pedestals. The pin
approach and key-tail clearance are retained. Each opening stop engages at 20°.

The new frame uses the revised 14.3 mm seats for bare 14.2 mm brass and a
1.2 mm split gap. It requires the matching caps supplied here. A CAD closure
check establishes seat contact before the clamp faces bottom out; it does not
establish actual gripping force. Fit without a liner and verify the printed
clamp holds. The previously requested cap-only fix for the old single-key frame
is not needed to assemble this longer three-key frame; the old single-key files
remain separate. Underside hex pockets now stop the M2 nuts turning.

## Hardware and assembly

- Three steel pins, 1 mm diameter × 12 mm long.
- Three compression springs, nominal 2 mm OD × 5 mm free length, assumed 2 mm
  solid length and 0.3 mm wire. Spring rates are still unknown.
- Six M2 bolts and six M2 nuts seated in underside hex pockets; check the existing bolt lengths fit.
- PETG frame, three caps and three keys; 2 mm EVA foam sheet and pad adhesive.
  No TPU part remains: the pad face is printed as part of each key.

Each fixed bearing bore is 1.1 mm for the requested fit trial; each moving bore
is 1.25 mm. Each peg is 1.5 mm long, tapering from 1.2 to 1.0 mm diameter. The
nominal spring seat spacing remains 2.8 mm closed and about 3.70 mm open.

Install pins in order **4, then 5, then 6**. Feed from the foot end through
lower empty bearing bores. A straight 1 mm wire used as an assembly pusher can
advance the upper pin through the lower bearings; remove it after seating each
12 mm pin. Do not fit the lower pins first, because they block that route.
The CAD checks this entire insertion sequence including previously seated pins,
keys, frame, caps, tube and nominal M2 head envelopes. Physical manipulation
and spring fitting still need a trial on this longer assembly.

## Print files

Open the 3MF as a project in Bambu Studio, select the actual material and bed
profiles, then slice and inspect supports. These files contain no G-code.

- `exports/three-key/whistle-three-key-P1S.3mf`: one PETG plate with all nine
  pieces - frame, three keys, three clamp caps, cutting guide and pin coupon.
  Every part is PETG, so there is no second plate and no material change.
- `exports/three-key/assembly-open.step`: complete assembly for review.
- `exports/three-key/assembly-closed.step`: the same assembly closed, for
  checking the pads against the whistle body.
- `exports/three-key/print-oriented/`: one file per distinct part. Print
  `lever_print` three times and `clamp_cap_print` three times. The earlier
  `lever4/5/6_print` files were byte-identical copies and are removed; any key
  fits any of the three positions.

The frame rests flat on its base. Keys rest on their finger faces and caps on
end faces. Supports are enabled for the frame and keys. PETG uses 0.16 mm
layers and four walls. Print three identical keys; no markings or sorting are
needed. The pad face prints as part of the key, so its surface finish matters:
keep the dished underside free of stringing before gluing the EVA.
The frame, caps, pins and springs are reusable, but the keys are new.

## Verification

`tests/test_three_key.py` checks measured positions, valid solids and export
round trips, 21 positions for each key, actual stop contact and overtravel,
1 mm open-airway clearance, seal coverage, at least 1 mm key/pad clearance to
caps, and the mounting and pin-insertion checks described above. Key-to-key
clearance is checked from axial extents, which remain invariant under their
hinge rotation, covering independent key combinations. Frame collision checks
use exact frame sections spanning the full invariant axial extent of each key.

The shared 3MF tests verify quantities, mesh integrity, materials, plate layout,
and preserved orientation for both single-key and three-key projects. CI builds
and tests both prototypes. These checks do not replace physical trials of grip,
finger access, print strength, spring feel or sound.

Regenerate and package from the repository root:

```sh
python scripts/build_ci.py --model three_key --output build/three-key
python scripts/package_3mf.py --three-key --source build/three-key --output build/three-key/whistle-three-key-P1S.3mf
```

The assembly STEP contains solid cylindrical spring envelopes for illustration.
They deliberately overlap the locating pegs and sockets; they are not printable
parts or a model of the coil wire. The separate printable parts pass solid and
mesh validation.

## Opposite-side frame rail

A 5 mm wide rail joins the two clamp bases on the side opposite the keys,
closing the frame to resist twisting. Both lower rails are flush with the
clamp-base bottoms, giving a continuous flat printing base. The rail stays
below the tube and outside its surface, preserving the cap split and pin route.
Only the frame needs reprinting relative to the first three-key version.
Physical stiffness and thumb comfort remain trial checks.

## Middle clamp between keys 5 and 6

A third clamp at 52.475 mm is centred in the measured 19.15 mm edge gap
between holes 5 and 6. Its cap is identical to the end caps. Six M2 bolt
passages are drilled through the completed frame, including the raised spine.
The movement, mounting and insertion checks include all three clamps.
Compared with the first three-key prototype, reprint the frame and one extra
cap, and add two M2 bolts and nuts. Existing keys, pads and two caps are reusable.
Both 3MF projects now contain eleven pieces and orient the frame flat on its base.

The raised hinge-side spine steps down locally at the middle clamp, with 0.2 mm axial clearance at each side, so the cap can seat and tighten. Both lower rails remain continuous.

## Underside M2 nut pockets

All six bolt positions have hexagonal pockets opening from the bottom of the
frame. Each pocket is 4.30 mm across flats and 1.90 mm deep. The default nut
is 4.00 mm across flats and 1.60 mm thick, matching this
[Accu M2 DIN 934 specification](https://www.accu.co.uk/hexagon-nuts/766417-NUT202M2).
Actual nut dimensions have not yet been confirmed by the player. Dimensions
and print clearance are parameters near the top of `scripts/three_key.py`.

Local 7 mm diameter bosses leave at least 1 mm material outside pocket corners
and a 1.6 mm bearing roof above each nut. Bolt centres and clamp interfaces are
unchanged. The frame stays flat on the bed; inspect and remove any support
inside the pockets before inserting nuts. Only the frame needs reprinting.

Insert nuts from underneath, flat against the pocket roofs, then engage the
bolts from above. The hex walls prevent rotation once engaged. These are open
pockets, not snap-fit retainers: a small piece of tape can hold a nut while
starting its bolt. Bolts can protrude farther below the frame with recessed nuts.

Tests check the full nut insertion sweep, fit at the seated position, contact
with the bearing roof, blocked rotation and material around each pocket.
Printed nut fit and resistance to tightening torque still need a physical trial.
The nut-pocket revision retained individual pad sizes. On 2026-09-09 the player
confirmed the measurements and requested identical parts for all three positions.
The shared pad is 12.30 mm OD; cup ID is 12.60 mm and head OD is 14.20 mm.
Minimum axial head-to-head clearance is 1.545 mm throughout rotation. The
common geometry is tested for interchangeability, travel and sealing coverage.
The larger hole-4 head still needs a playing trial for finger comfort.

## Pad locating tabs — 2026-09-09

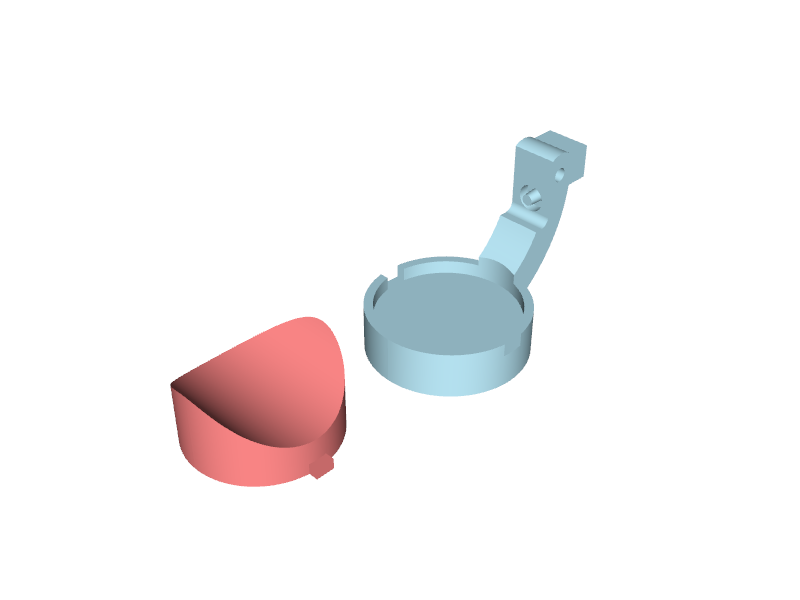
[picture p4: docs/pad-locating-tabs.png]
Pad tabs and retaining-ring notches


All three common keys now have two opposed notches in the retaining ring,
aligned along the whistle axis. Each TPU pad has matching tabs, 1.6 mm wide,
0.9 mm thick and extending 0.75 mm beyond its 12.30 mm circular body. Overall
pad length across tabs is 13.80 mm, within the 14.20 mm key-head envelope.
Notches are 2.0 mm wide, giving 0.20 mm nominal clearance on each side.

The notches open from the pad side through the ring's 1.2 mm height. The tabs
are flush with the flat glue backing; the solid cup roof remains the seating
stop. Align the tabs with the notches and press the backing fully against the
roof before gluing. A 180-degree reversal is equivalent; a 90-degree rotation
is blocked. These are locating features, not snap-fit retainers.

The tabs sit above the tube crown and do not interrupt the curved sealing
face. Printing orientation stays the same: keys finger-face down, pads flat
back down. Print the new keys and pads together; reuse the frame and hardware.
Tests cover tab insertion, correct/incorrect orientation, full seating,
interchangeability, key travel and the continuous sealing band. Confirm the
nominal tab clearance in the PETG/95A TPU printing trial.

## Clamp cap flat-end correction — 2026-09-09

The previous 4 mm curved band was centred between 6 mm bolt tabs. With a tab
end on the bed, the curved band started 1 mm in mid-air. That orientation was
incorrect for support-free printing; disabling supports did not make it printable.

The bed-facing tab ends now finish flush with the curved band. Tab axial width
is 5 mm, from -2 to +3 mm relative to the bolt centres; the opposite ends retain
their previous positions. Ring width, ring position, bolt centres and clamp gap
are unchanged. The shortest axial ligament beside a 2.4 mm bolt bore is 0.8 mm;
check the PETG tabs during tightening. Print the supplied orientation, with the
complete flat C-shaped end on the bed. The small horizontal bolt bores still
require short bridges, but the curved band no longer starts unsupported.

A first-layer section test verifies one connected full-profile footprint, rather
than two disconnected bolt-tab islands. Reprint only the three clamp caps. The
frame, keys, pads and hardware remain compatible.

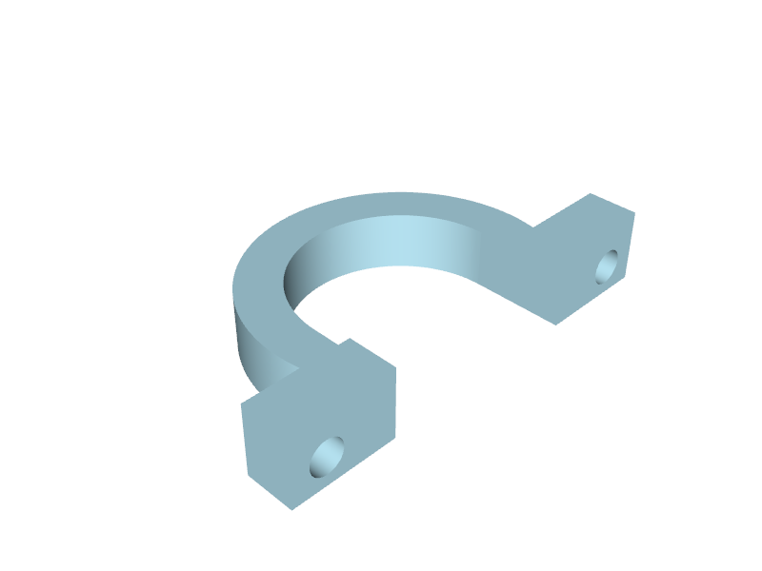
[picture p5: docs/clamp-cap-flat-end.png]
Clamp cap with complete flat bed face


## Integral pad face for 2 mm EVA — 2026-09-11

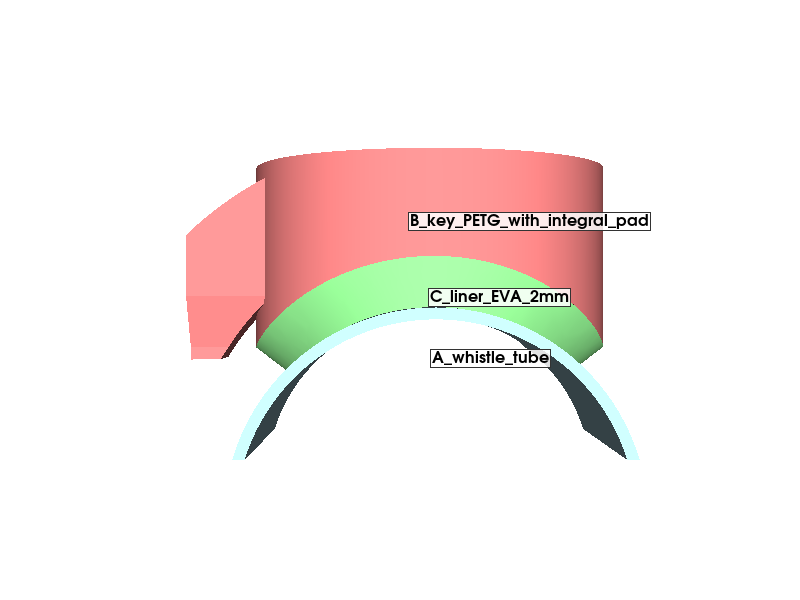
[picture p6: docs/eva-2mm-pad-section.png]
Closed pad section at hole 5


The separate TPU carrier, its retaining ring and the locating tabs are removed.
Each key now has a dished pad boss printed as part of the key, and the 2 mm EVA
liner is glued straight into it. The sections above describing the 12.30 mm
carrier, the 12.60 mm cup and the pad tabs are superseded.

The dish is a cylinder of 8.9 mm radius concentric with the whistle at closure
(7.1 mm tube radius, less 0.2 mm interference, plus the 2 mm sheet). The glue
surface is a single continuous face of 175.69 mm² with no ring, notch or step
in it, and 3.8 mm of solid PETG sits above it. The pad face stays 14.2 mm
across, so head-to-head clearance remains 1.545 mm.

Using the full 14.2 mm face instead of a 12.3 mm carrier more than offsets the
thicker sheet: the continuous seal band is 3.04 mm at hole 4, 1.68 mm at hole 5
and 1.78 mm at hole 6, against 2.29, 1.55 and 1.65 mm for the 1 mm liner. Key
volume rises from 749 to 957 mm³. Opening, stop, spring seats, hinge, frame and
clamps are unchanged: pad-centre lift is still 4.670 mm at 35°.

Printed parts drop from ten to five files and the build is now entirely PETG,
so no TPU spool is needed. The three keys were identical copies, so they are
exported once as `lever_print` and printed three times, as the clamp cap
already was. The cutting guide and its 3MF are resized: the traced
outline is 14.59 × 14.20 mm. Reprint the three keys and the cutting guide, cut
three new liners, and reuse the frame, caps, pins, springs and hardware.

## 3 mm spring variants — 2026-09-11

`scripts/three_key.py` now carries a spring table and builds three variants from
one source. `scripts/build_ci.py --model` selects them; run on its own the file
still builds the 2 mm mechanism.

| variant | coil | opening | seat Z | collar gap | preload | pad lift | open pad to tube |
|---|---|---|---|---|---|---|---|
| `three_key` | 2.0 × 5.0 | 35° | 3.10 | 0.577 | 0.376 | 4.670 | 4.042 |
| `three_key_3mm_spring` | 3.0 × 6.0 | 35° | 3.70 | 0.291 | 1.022 | 4.670 | 4.042 |
| `three_key_3mm_short_spring` | 3.0 × 5.0 | 30° | 3.52 | 0.214 | 0.407 | 4.300 | 3.450 |

The coil axis passes over the pivot, so clearance to the reinforced hinge collar
is the perpendicular distance from the pivot to that axis, less the collar's
1.525 mm radius and the coil radius. A 3 mm coil takes 0.5 mm more than a 2 mm
one, and the worst case is at full opening where the coil is most tilted. The
seat must rise to compensate, which lengthens the swing and spends preload.

With a 5 mm free length that trade runs out at 30°: 31° needs a 3.56 mm seat to
hold 0.2 mm clearance, and preload there falls to 0.330, below the 0.35 standard
the 2 mm build meets. A 6 mm free length removes the conflict entirely and keeps
the full 35° opening with 1.022 mm preload.

Changing the coil changes the frame seat (4.2 mm wide, 3.4 mm bore) and the key
peg (1.8 tapering to 1.5 mm), so each variant has its own frame and keys. The
pad face, EVA liner, cutting guide, hinge, clamps and hardware are identical
across all three. Solid heights are assumptions: measure the actual coils, since
the retained 2.8 mm closed spacing allows at most 2.3 mm solid.

## Closure over-travel for the leaking seals — 2026-09-11

The player trial reported that the pads do not seal reliably enough to play.
The cause is not pad size or spring force: nothing hard-stops the key at
closure, so finger force should compress the foam, but the key landed on the
top rear corner of the spring holder only 1.22° past nominal closure. That
capped foam compression at 0.44 mm, 22% of the 2 mm liner, however hard the key
was pressed — and 0.1 mm of PETG oversize in that corner takes it back to the
0.2 mm design figure, or 10%. Foam needs roughly 25-40% compression to conform
to a hole rim, so the seal was marginal by design and varied between keys.

The key's spring-housing relief goes from 0.3 to 0.8 mm. The key can now be
pressed 9.36° past nominal closure before touching anything, which is 1.82 mm
of pad travel; at a working 3° the pad moves 0.59 mm for 0.79 mm total
compression, about 39% of the liner, with 1.21 mm still left to the tube. The
foam is now genuinely the only stop. The arm width blend tracks the relief so
the transition fillet keeps its constant-width edge, and the reinforcement
checks are unchanged. Key volume falls from 956.5 to 944.8 mm³.

Reprint the three keys; the frame, caps, liners and hardware are unaffected.
A test pins the over-travel so this cannot silently regress.

If the seal is still poor after this, the remaining levers are, in order: seat
the liners by holding the keys closed overnight, as woodwind pads are seated;
then narrow the pad along the whistle, where the band is 3.20 mm against
1.76 mm across it. Trimming the along-tube dimension from 14.2 to 10 mm nearly
doubles contact pressure, because the hole itself carries no load. A leak that
appears on one side only is hinge slop, not compression, and needs the pin fit
addressed instead.

## Ergonomic key tops — 2026-09-12

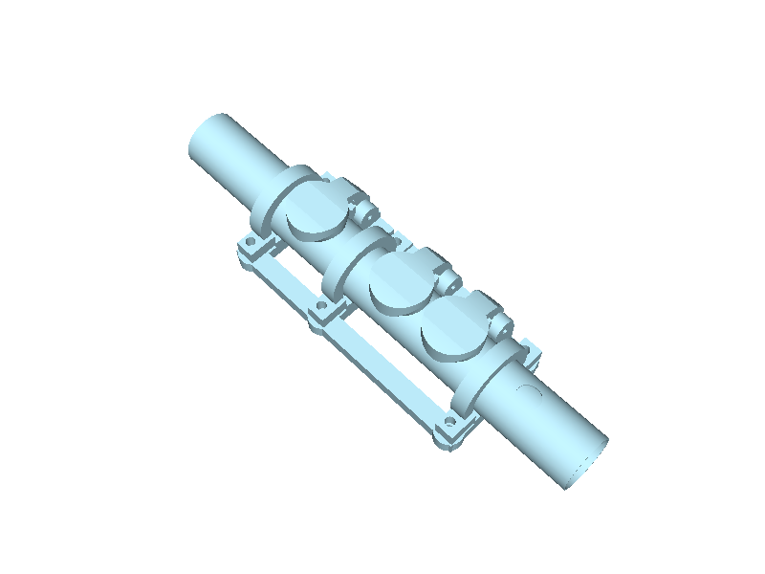
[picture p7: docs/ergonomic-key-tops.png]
Three-key assembly with the lowered finger faces


The overnight seating trial fixed the seals, so the keys are now shaped for the
finger. The pad boss ran out to the arm's own crown, leaving a flat-topped drum
standing proud of the arm: 725 mm³ of PETG above the recess, 77% of the key,
7.33 mm thick at the pad rim against 3.80 mm at its centre.

The finger face drops to a flat plane 11.0 mm from the tube axis, 3.9 mm above
the whistle, with a 1.5 mm chamfered rim. The plane is close to tangent to the
arm's curve, so the arm rises into the face rather than stepping against it.
The cut runs across the whole key because the reinforced arm reaches radius
13.7, higher than the finger face; the bend the strength tests probe sits at
z 7.5-8.5 and is untouched.

| | before | after |
|---|---|---|
| key volume | 944.8 mm³ | 635.9 mm³ (-33%) |
| PETG above the recess, centre | 3.80 mm | 2.10 mm |
| finger face | flat disc, square rim | 25 mm crowned cylinder |
| print height | 14.7 mm | 13.0 mm |
| bed contact printing face down | 158 mm² | 87 mm² |

The pad face, EVA recess, liner, hinge, spring interfaces and opening are
unchanged, so the seal and travel behaviour carry over untouched, as does the
0.79 mm of closure compression. All three spring variants get the same top.
Reprint the three keys; reuse the frame, caps, liners, pins and springs.
### Crowned face, 2026-09-12

The flat face, its rim chamfer and the faceted reinforcement crown are replaced
by a single cut: a cylinder of 25 mm radius about the tube axis, truncated by a
0.2 mm flat landing at the apex so the part still starts on the bed. One smooth
surface now runs from the arm over the pad, and the angular shoulder above the
arm reinforcement is gone.

The crown must be cylindrical, not spherical. The EVA recess is a cylinder
about the same axis, so it does not vary along the whistle; a spherical crown
does, and closes on the recess at the pad's axial edges, leaving 1.30 mm of
PETG there against the 2.10 mm a cylindrical crown holds everywhere. The
radius is set by the arm bend the strength tests probe at z 7.5-8.5, which the
crown must stay above: 25 mm clears it, 20 mm cuts into it.

The pad's two axial edges are left square where the crown meets the 14.2 mm
side wall. Rounding them would eat into that 2.10 mm wall.

### Earlier flat face

The rim relief chamfers the finger face's own boundary, not the pad circle.
Relieving the circle cut a 1.4 mm trench between the arm and the pad, because
the arm reaches the face at full height: at y = 0 the surface ran 11.00 on the
arm, down to 9.60, then back to 11.00 on the pad. Chamfering the face edges
leaves that junction continuous and only softens the free rim.

A test pins the flat face, its area, the relieved rim, and that the surface
never dips on the way from the arm into the pad.

## Opening reduced to 27 degrees — 2026-09-12

The player measured about 6 mm of gap above an open hole and asked for 2 mm
less. The figure the earlier notes quoted, 4.042 mm, is the minimum three
dimensional distance from the liner to the tube, which occurs off to the side
at the pad's trailing edge. Straight up over the hole, where it is actually
measured, the 35 degree opening gives 5.94 mm. The model and the instrument
agree; only the quoted quantity was wrong.

Opening drops from 35 to 27 degrees on all three variants.

| | 35 deg | 27 deg |
|---|---|---|
| gap straight up over the hole | 5.94 mm | 4.78 mm |
| finger travel (pad lift) | 4.670 mm | 4.027 mm |
| minimum 3-D liner to tube | 4.042 mm | 3.090 mm |
| spring preload, 2 mm coil | 0.376 mm | 0.772 mm |
| spring preload, 3 x 6 mm coil | 1.022 mm | 1.495 mm |
| spring preload, 3 x 5 mm coil | 0.407 mm | 0.578 mm |

27 degrees gives 1.16 mm of the 2 mm asked for. A full 2 mm needs 22 degrees,
which drops the minimum three dimensional clearance to 2.48 mm and breaks the
3 mm rule; 27 degrees keeps it at 3.09 mm. Preload roughly doubles on the 2 mm
coil, so the return action should be more positive.

Only the frame changes: the opening stop is part of the frame, and the key
geometry does not depend on the angle. Reprint the frame alone and reuse the
keys, caps, liners, pins, springs and hardware. Whether the smaller opening
affects the tone of these notes is a playing question; CAD cannot answer it.

## Key fracture at the 60-65 degree station — 2026-09-12

A key fractured before it was even played, on the outside of the curve roughly
level with the spring housing. The cause was the closure over-travel fix: the
spring-housing relief was opened from 0.3 to 0.8 mm in both x and z, and the x
component cut the arm from the inside exactly where bending stress peaks.

Bending stress index M/Z along the arm, with the finger load on the pad and the
reaction at the pivot:

| station | before the relief change | after it | now |
|---|---|---|---|
| 60 deg | Z 10.04, stress 0.97 | Z 5.59, stress 1.74 | Z 5.63, stress 1.72 |
| 65 deg | Z 4.86, stress 2.09 | Z 2.77, stress 3.66 | Z 7.44, stress 1.37 |

The two probes that were supposed to guard the bend sit at 55 and 70 degrees,
either side of the damage, so nothing failed.

Two changes. The relief is split: 0.3 mm in x as before, 0.8 mm in z. The
over-travel comes almost entirely from the z component, so this keeps 3.58
degrees past nominal closure and the full 0.79 mm of foam compression while
restoring most of the section. Then `upper_arm_radial_extra` goes from 1.0 to
1.8 mm, replacing the remaining stock outboard where it costs nothing over the
holes; the arm's outer radius goes 13.7 to 14.5 mm on the hinge side only.

Peak stress ends up 1.37 against 2.09 for the version that survived playing,
so the arm is about 35% less stressed than before any of this. Key volume
635.9 to 663.9 mm3. The test now probes the 60 and 65 degree stations directly,
inboard and outboard, across the arm width.

Reprint the keys. The frame, caps, liners, pins, springs and hardware are
unchanged by this revision.

### Rounding the notch staircase

Restoring the section was not the whole story. A section through the arm at the
fracture station showed a staircase of sharp inside corners where the spring
clearance channel meets the housing relief and where the peg leaves the arm:
nine line-to-line corners between x -13 and -8. Station 65 degrees, where the
key broke, sits at (-10.11, 4.72), directly on that staircase. A sharp
re-entrant corner concentrates stress whatever the section area is, and in a
printed part it also lands between extrusion paths.

Three of those corners are now rounded: the channel top where it meets the
relief face (0.6 mm), the channel's far end (0.5 mm) and the peg root (0.6 mm).
Nine sharp corners become three, and the survivors are the peg tip, which
carries no load, and one on the tail away from the bend. Key volume 663.9 to
666.4 mm3.

Two practical notes. The radii are tried largest-first with a fallback, because
each variant's coil size changes what OCCT will accept. And the fillets must be
applied before the crown cuts: build123d's fillet works from the edges' parent
solid, so running them afterwards silently discarded the flat landing and left
the key with no printable face.

### A notch the fracture fix introduced — 2026-09-13

Raising `upper_arm_radial_extra` from 1.0 to 1.8 to restore the arm section
also raised `reinforced_r` from 13.7 to 14.5, and the back web is built tangent
to the arm at that radius. The tangent point dropped from z 6.396 to z 4.221,
below `arm_reinforcement_full_z` of 6.0 — so the web now met the arm while the
arm was still ramping up to full radius. Instead of touching, the two surfaces
crossed, leaving a 48.9° sharp re-entrant V at (-12.951, 4.221). The opening
stop spans x -13.7 to -12.2, so the notch sat in the middle of the impact zone.

The tail profile before the change was a single 5.54 mm line from (-14.70, 1.50)
to (-12.115, 6.396); afterwards it was four segments with the V in the middle.
Spotted in a draftwright drawing of the key, not by any test.

`arm_reinforcement_full_z` drops to 4.0, at or below the tangent height, so the
arm is at full radius where the web meets it. The tail returns to two segments,
and Z at the 60 and 65 degree stations is unchanged at 10.03 and 7.44. An
assert now requires `tangent_z >= arm_reinforcement_full_z`.

A general guard replaces the positional checks: the XZ profile is walked and
every line-to-line corner classified convex or re-entrant by probing along its
bisector. Re-entrant corners must leave a void wedge of at least 90°. The
current profile has no re-entrant corners at all; with the old ramp the guard
reports 49.0° at (-12.95, 4.22). This would have caught both this notch and the
original spring-housing staircase.

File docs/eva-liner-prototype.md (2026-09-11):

# 35° opening and 2 mm EVA liner prototype

The three identical keys open to 35°. The 2 mm EVA foam sheet is now glued
directly to the key: there is no separate TPU carrier, no retaining ring and no
locating tabs. The pad face is part of the printed PETG key. The existing
2 mm OD × 5 mm compression springs, 1 × 12 mm pins and M2 hardware are retained.

Closed pad section at hole 5

## Integral pad face

Each key carries a dished boss on its underside. The dish is a cylinder of
8.9 mm radius, concentric with the whistle when the key is closed, which is
the 7.1 mm tube radius less 0.2 mm closure interference plus the 2 mm sheet.
The EVA fills that dish and seals against the brass.

- The glue surface is one continuous cylindrical face, 175.69 mm², with no
  ring, notch, step or parting line anywhere on it.
- 3.8 mm of solid PETG sits above the dish, so the key is its own pad backing.
  The earlier arrangement left a 0.8 mm TPU shell doing that job.
- The pad face is 14.2 mm across, the same envelope as the old retaining ring,
  leaving 1.545 mm between adjacent pads.
- Key volume rises from 749 mm³ to 957 mm³. The printed part count drops from
  ten files to five, since the three identical keys now export once as
  `lever_print`, and the TPU spool is no longer needed.

Because the whole 14.2 mm face is available for foam, the sealing footprint is
wider than the old 12.3 mm carrier gave, despite the thicker sheet. The
continuous band of foam around each hole at the nominal mid-compression
surface is 3.04 mm at hole 4, 1.68 mm at hole 5 and 1.78 mm at hole 6. The
previous 1 mm liner in a TPU carrier gave 2.29, 1.55 and 1.65 mm.

## Opening and spring limits

At the nominal open stop, pad-centre lift is 4.670 mm, the uncompressed EVA
surface clears the whistle by 4.042 mm and the key itself clears it by
2.270 mm. Closed spring length remains 2.8 mm; open length is 4.624 mm,
leaving 0.376 mm nominal compression against a 5 mm free length. The spring
rate is unknown, so this does not establish the actual return force.

CAD clearance cannot establish whether the pads affect tone. Compare each open
note with the unkeyed whistle, then check rapid release and comfortable closing
travel. The return force and sound need a playing test before this becomes a
settled design.

## Cutting and fitting the EVA

Print the cutting guide in PETG, with its flat base on the bed. It is included
on the PETG parts plate and supplied separately as `eva-cutting-template.3mf`.
The raised grip makes it easier to hold while tracing its outside edge.

1. Trace the guide onto the 2 mm EVA sheet and cut around the line. Make one
   liner first to check the fit, then repeat for the other two keys.
2. The outline is approximately 14.59 × 14.20 mm. Its long direction, parallel
   to the grip, goes **across** the whistle; its short direction runs along it.
3. Curve it into the dished face on the underside of the key. It covers the
   whole face: do not cut a hole in its centre. Check the edge alignment
   before gluing.
4. Use a thin, even glue layer suitable for the actual EVA and PETG. Keep glue
   off the sealing surface.
5. Test one pad for leakage and reliable opening before fitting all three.

The guide is an unrolled outline at the sheet's mid-thickness radius rather
than a flat projection of the curved pad, so it is wider across the whistle
than the 14.2 mm pad face. Nominal closure assumes 0.2 mm EVA compression;
foam hardness and adhesive thickness are not measured, so this is a prototype
allowance, not a proven seal pressure.

## Printing and verification

Every printed part is now PETG: frame, three keys, three clamp caps, cutting
guide and pin coupon. `whistle-three-key-P1S.3mf` puts all nine on a single
plate. Existing support settings for the frame and keys are retained. The
guide prints flat without supports.

Automated checks cover 21 travel positions per key, stop engagement, spring
solid-length margin and at least 0.35 mm preload, 0.2 mm spring/hinge
clearance, open airway, at least 3 mm open pad clearance, a 1.5 mm seal band
around each hole, a single uninterrupted glue face, printable solids and the
cutting-guide outline. These verify the nominal CAD model, not printing
tolerances, fatigue strength or acoustic results.

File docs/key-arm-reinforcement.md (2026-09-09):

# Key arm reinforcement — 9 September 2026

The user reported broken keys and supplied a photo showing an intact pad cup and TPU pad with a short arm fragment still attached. The photo supports investigating the curved arm; it does not establish the exact fracture plane, loading history or whether layer adhesion contributed.

The upper arm now grows from the existing 4 mm width to 6 mm between Z = 5.5 and 7.5 mm. Up to 1 mm of radial stock is added on the outside of the curve, giving a 4 mm radial section in the fully reinforced region. The reinforcement starts at Z = 3.4 mm, above the fixed bearing heads, and tapers into the original profile. The cup's top height and pad seat are retained.

The hinge hub, pin bore, opening-stop tail, spring peg, spring interfaces and pad geometry are unchanged. All three keys use the same geometry. Numerical comparison with the previous key found no removed material; added stock lies between Z = 3.4 and 12.095 mm, on the upper arm. Key volume increases from 658.4710 to 732.4115 mm³, about 11.2%.

MCP solid validity and STEP export gates pass. Printability analysis reports two overhang warnings and one thin-wall warning, with no errors. The existing print package retains supports for the keys, four walls and 0.16 mm layers. This report does not certify the reinforcement's physical strength. The first replacement should be trialled in the existing frame before relying on a full set.

The regression suite checks actual added stock at two bend sections, the existing 4 mm hinge envelope, full key travel, spring and pin access, pad seating, interchangeability and exports. The accompanying image shows original material in blue and added material in red.

Validation completed: the 20 existing three-key tests passed. The new reinforcement test passed after correcting its handling of a multi-piece section result; no geometry change was needed for that test correction. All four print-package tests also passed.
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

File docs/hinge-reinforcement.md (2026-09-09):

# Hinge support reinforcement — 9 September 2026

A fixed hinge support broke while the user inserted its steel pin. The exact fracture location has not yet been confirmed. This revision adds stock around the bore and along the stem, with a lead-in to reduce snagging during insertion.

| Feature | Previous | Revised |
|---|---:|---:|
| Rounded fixed bearing head diameter | 4 mm | 6 mm |
| Stem width above the broad pedestal | 4 mm | 6 mm |
| Bearing axial thickness | 3 mm | 3.2 mm |
| Radial material above working bore | 1.45 mm | 2.45 mm |
| Pin entry lead-in | None | 0.25 mm deep, 45° each end |
| Straight working bore | 1.1 mm | 1.1 mm |
| Pin | 1 × 12 mm | 1 × 12 mm |
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

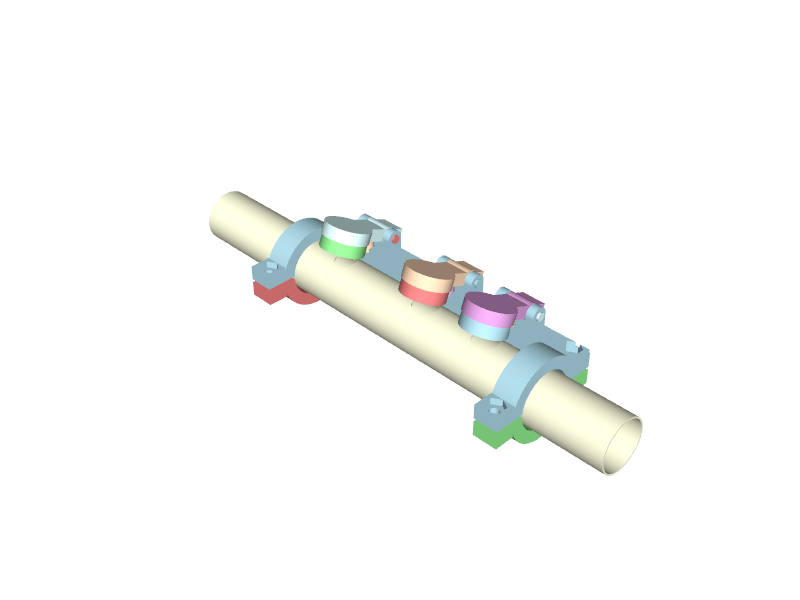
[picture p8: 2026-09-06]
docs/concept-open.png

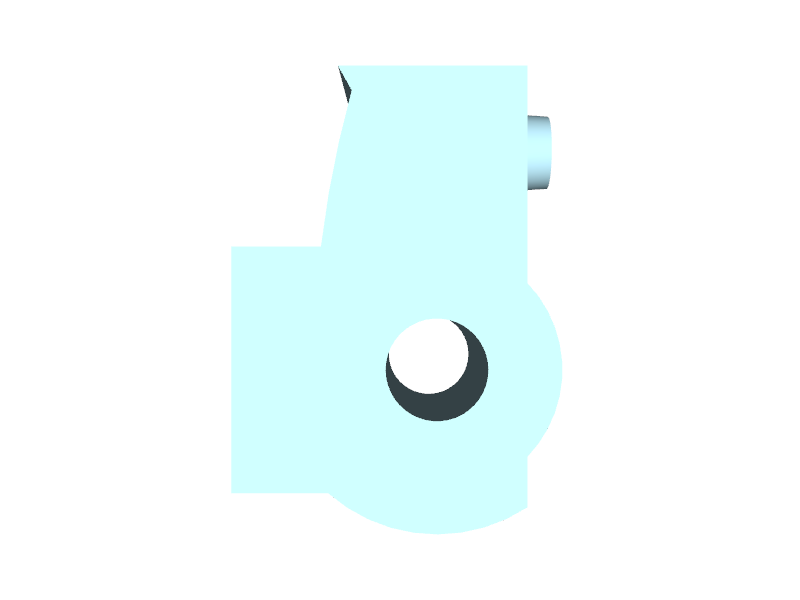
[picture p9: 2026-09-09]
docs/key-hinge-collar.png

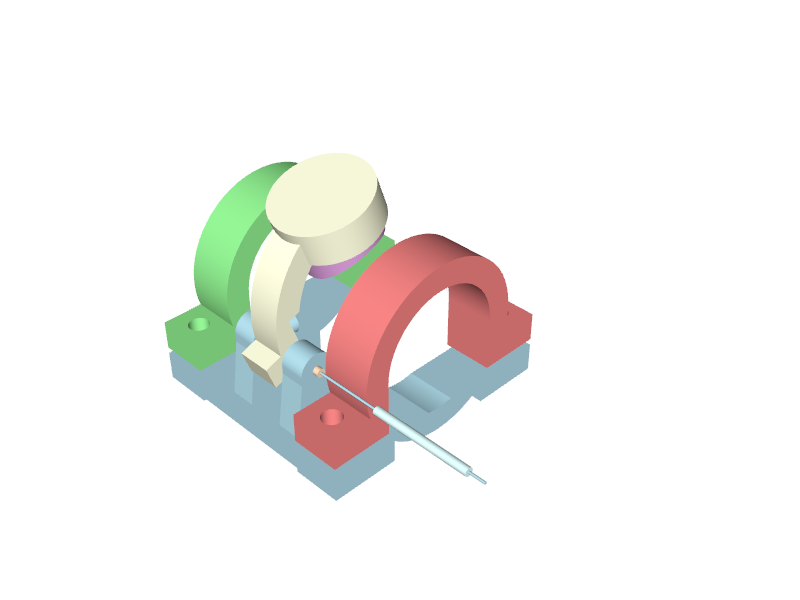
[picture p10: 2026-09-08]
docs/pin-insertion.png

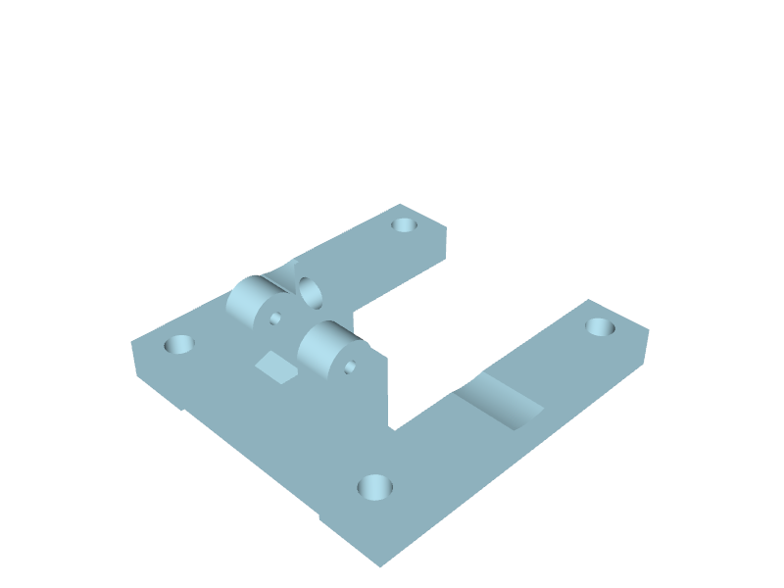
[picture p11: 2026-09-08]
docs/joined-clamp-base.png

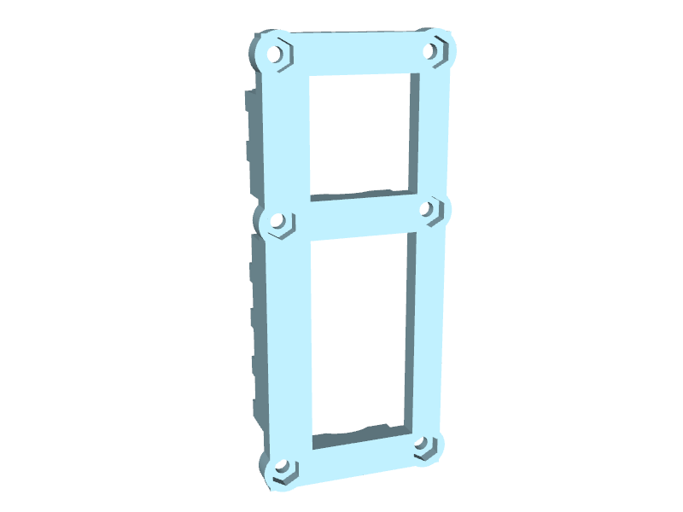
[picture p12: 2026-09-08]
docs/three-key-nut-pockets.png

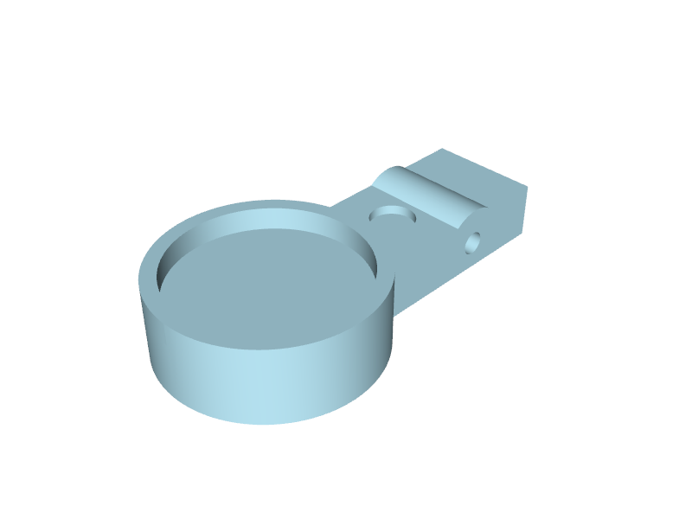
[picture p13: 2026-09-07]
docs/pad-retaining-ring.png

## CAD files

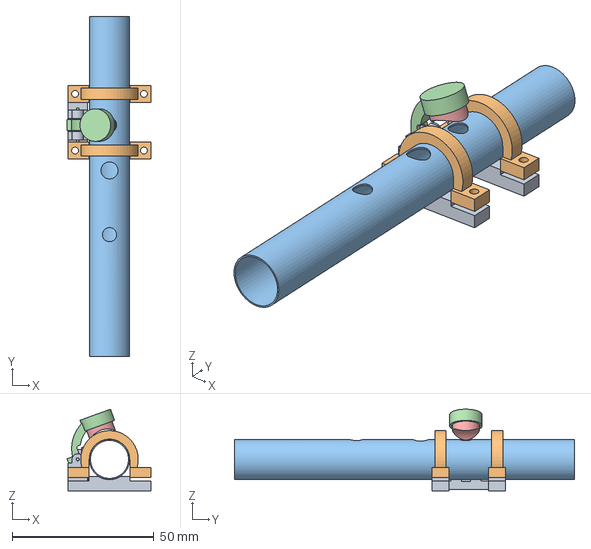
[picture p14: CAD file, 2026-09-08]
exports/single-key/assembly-open.step
29.7 x 120.0 x 28.8 mm

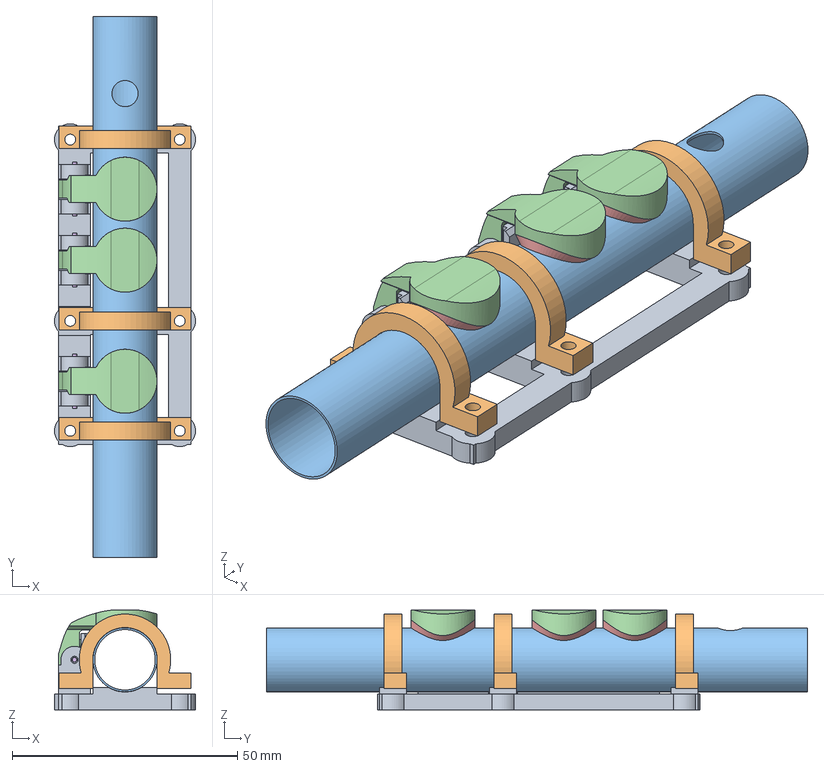
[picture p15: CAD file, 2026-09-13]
exports/three-key-3mm-spring/assembly-closed.step
31.3 x 120.0 x 22.1 mm
frame
clamp_cap_0
clamp_cap_1
clamp_cap_2
reference_tube
lever_blank4
lever_blank5
lever_blank6
eva_liner4
eva_liner5
eva_liner6
pin4
pin5
pin6

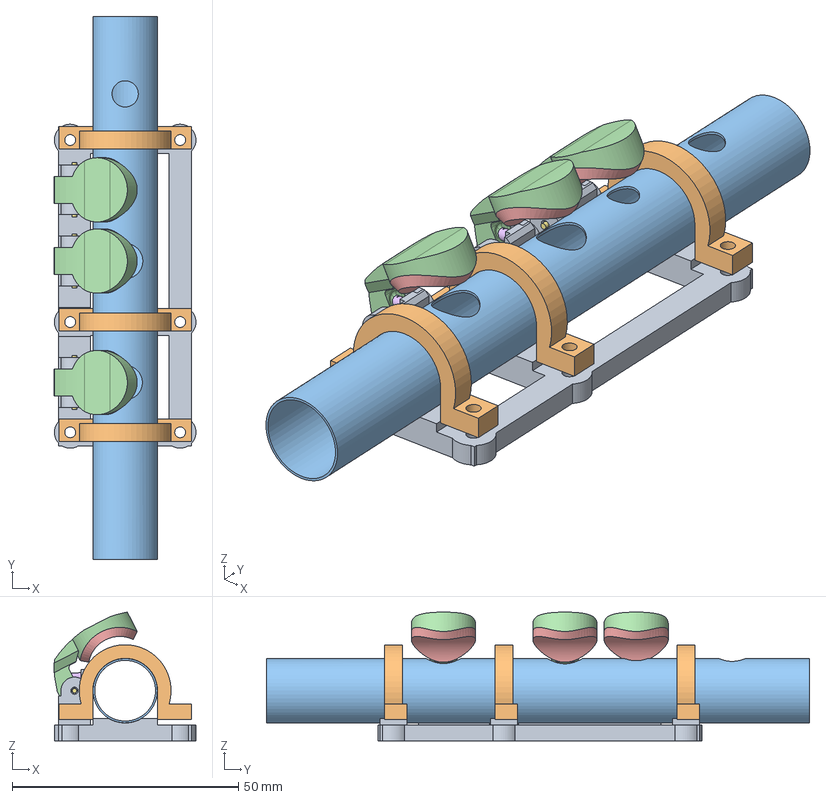
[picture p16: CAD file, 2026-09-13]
exports/three-key/assembly-open.step
31.4 x 120.0 x 28.5 mm
frame
clamp_cap_0
clamp_cap_1
clamp_cap_2
reference_tube
key4
key5
key6
foam_liner4
foam_liner5
foam_liner6
spring_envelope4
spring_envelope5
spring_envelope6
pin4
pin5
pin6

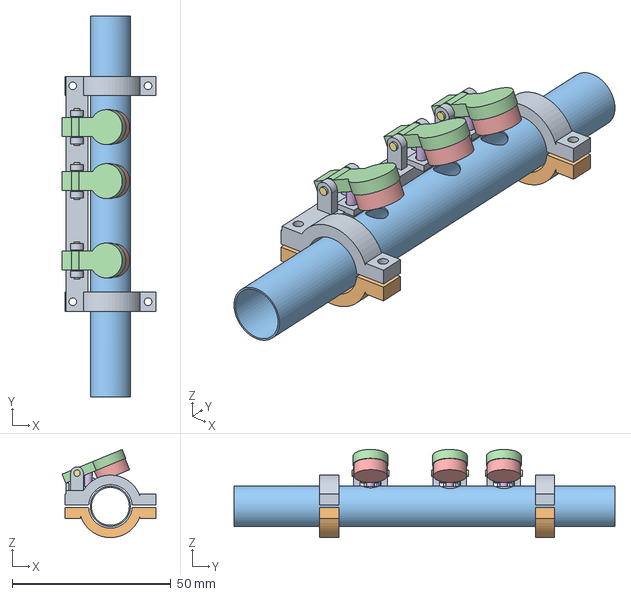
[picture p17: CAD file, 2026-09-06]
exports/assembly-open.step
29.6 x 120.0 x 27.8 mm

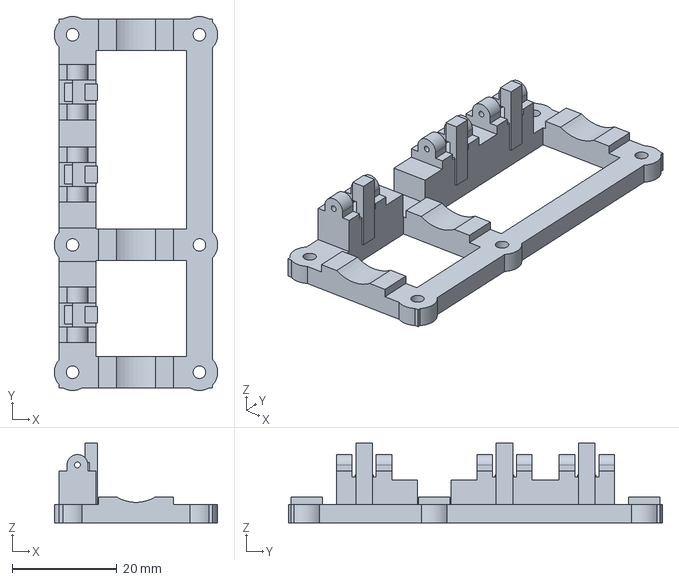
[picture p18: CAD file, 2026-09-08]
drawings/titanium/frame-reference.step
31.3 x 71.6 x 15.3 mm

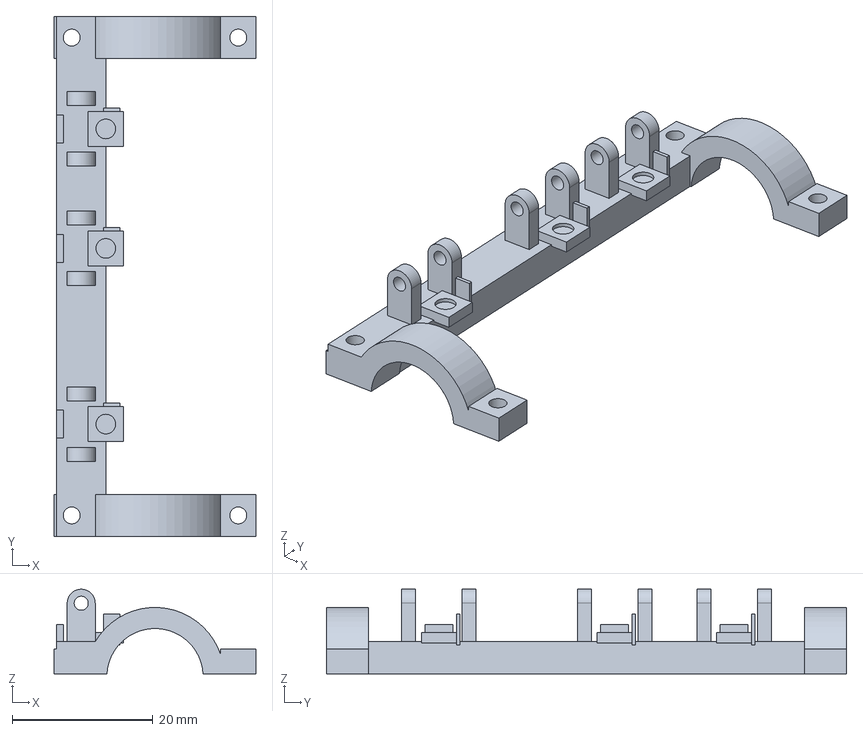
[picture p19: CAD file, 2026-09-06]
exports/frame.step
28.7 x 74.0 x 12.0 mm

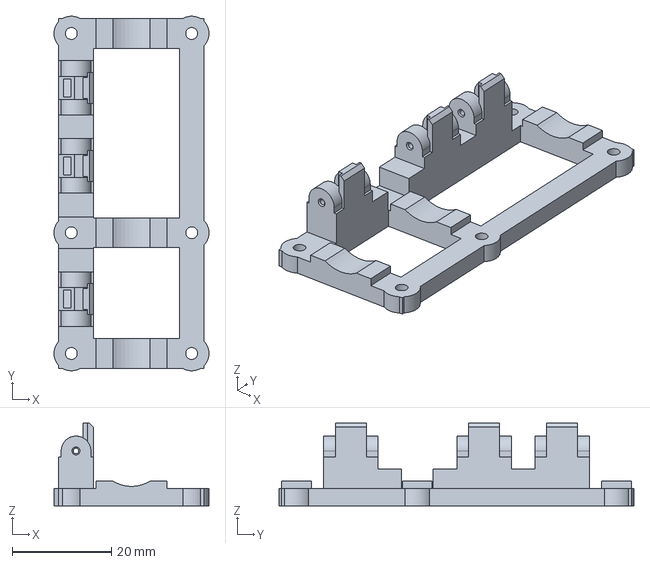
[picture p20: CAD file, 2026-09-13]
exports/three-key-3mm-short-spring/print-oriented/frame_print.step
31.3 x 71.6 x 16.7 mm

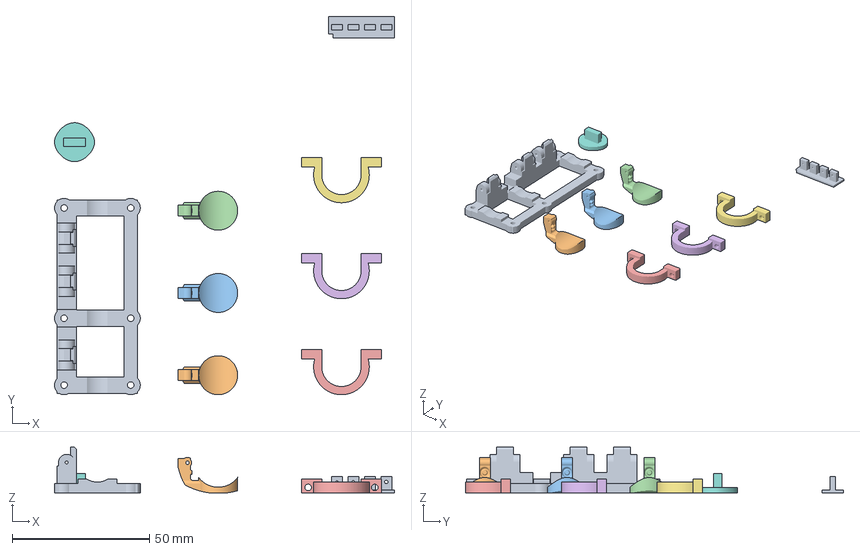
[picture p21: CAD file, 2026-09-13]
exports/three-key-3mm-short-spring/whistle-three-key-3mm-short-spring-P1S.3mf
124.0 x 138.0 x 16.7 mm
Three-key frame - flat base down
Common key 1 - finger face down
Common key 2 - finger face down
Common key 3 - finger face down
Clamp cap 1 - end face down
Clamp cap 2 - end face down
Clamp cap 3 - end face down
EVA liner cutting guide - flat base down
Pin fit coupon

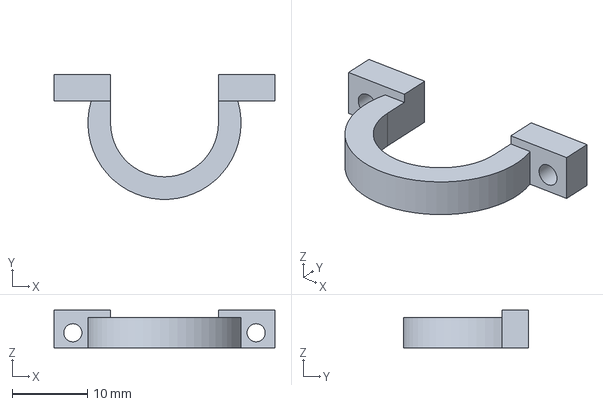
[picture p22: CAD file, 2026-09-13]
exports/three-key-3mm-spring/print-oriented/clamp_cap_print.step
29.3 x 16.5 x 5.00 mm

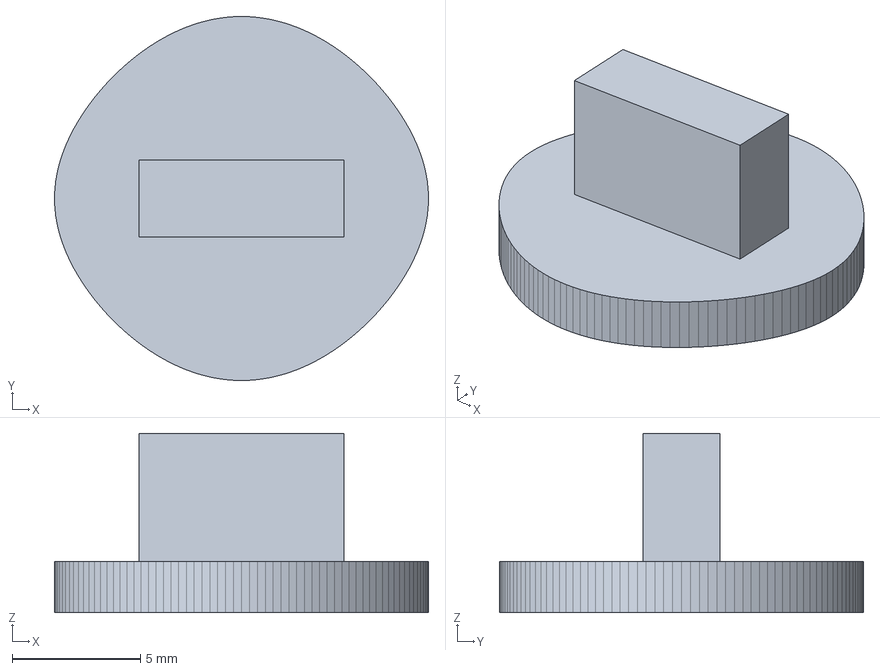
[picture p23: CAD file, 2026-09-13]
exports/three-key/print-oriented/eva_cutting_template.step
14.6 x 14.2 x 7.00 mm

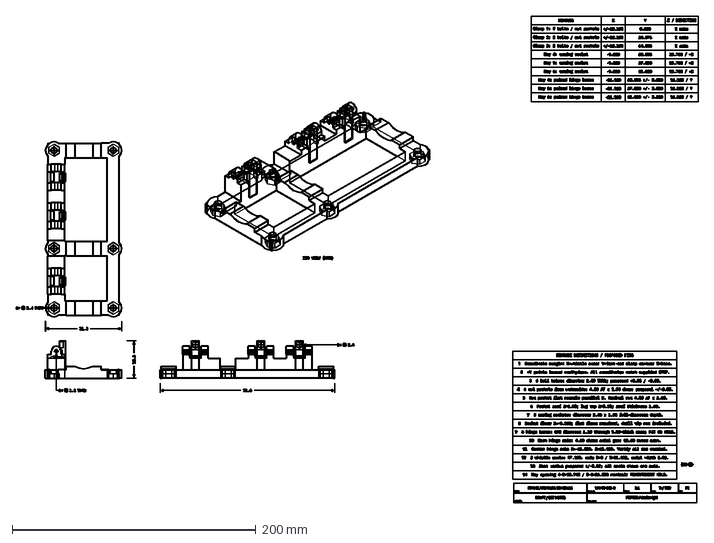
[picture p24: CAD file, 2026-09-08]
drawings/titanium/frame-features.dxf
559.2 x 399.1 mm

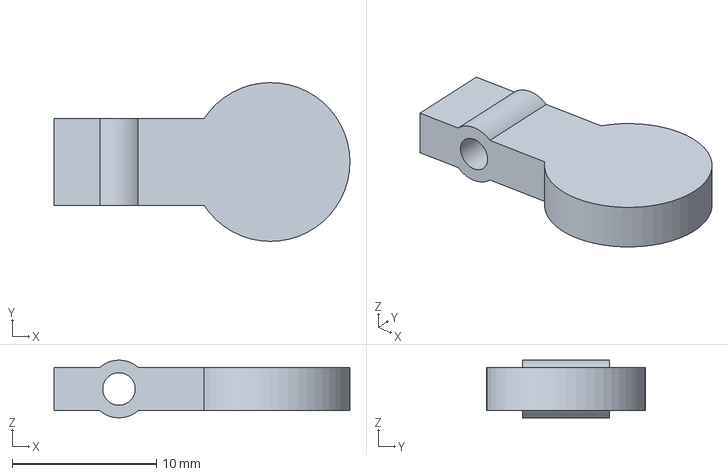
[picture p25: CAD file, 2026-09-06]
exports/lever_blank.step
20.5 x 11.0 x 4.00 mm

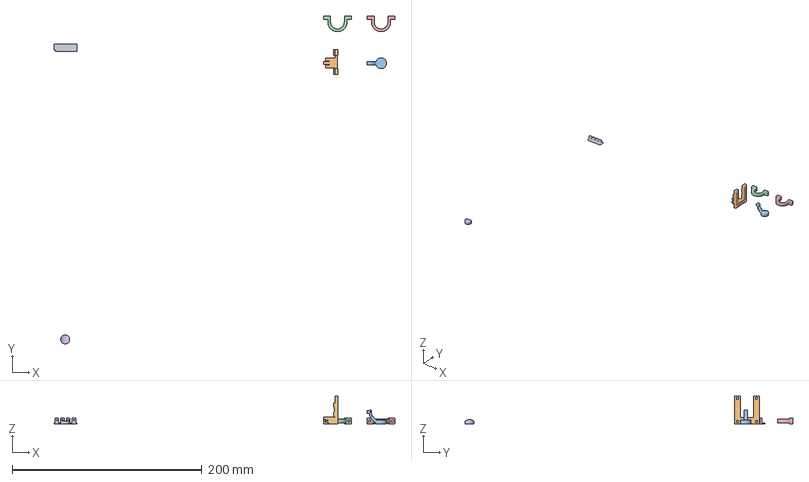
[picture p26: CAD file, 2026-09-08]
exports/single-key/whistle-key-P1S.3mf
359.5 x 345.7 x 29.4 mm
Pin fit coupon
Frame - outer rail side down
Key - finger face down
Clamp cap 1 - end face down
Clamp cap 2 - end face down
TPU pad - flat back down

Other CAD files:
exports/three-key-3mm-short-spring/assembly-open.step
exports/three-key-3mm-spring/assembly-open.step
exports/three-key-3mm-short-spring/assembly-closed.step
exports/three-key/assembly-closed.step
exports/three-key-3mm-short-spring/print-oriented/eva_cutting_template.step
drawings/titanium/frame-general.dxf
exports/clamp_cap_0.step
exports/clamp_cap_0.stl
exports/frame.stl
exports/lever_blank.stl
exports/single-key/clamp_cap_0.step
exports/single-key/clamp_cap_0.stl
exports/single-key/frame.step
exports/single-key/frame.stl
exports/single-key/lever_blank.step
exports/single-key/lever_blank.stl
exports/single-key/print-oriented/clamp_cap_print.step
exports/single-key/print-oriented/clamp_cap_print.stl
exports/single-key/print-oriented/frame_print.step
exports/single-key/print-oriented/frame_print.stl
exports/single-key/print-oriented/lever_print.step
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

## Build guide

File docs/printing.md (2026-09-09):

# Printing the single-key prototype

## All-PETG dry fit

Open [`whistle-key-P1S-dry-fit-PETG.3mf`](../exports/single-key/whistle-key-P1S-dry-fit-PETG.3mf)
as a project in Bambu Studio. This is the player's requested dry run: all six
pieces are PETG, including the normally flexible pad.

The single plate contains one frame, one key, two identical clamp caps, one
rigid pad and one pin-fit coupon. Each mesh is already oriented and on the bed.
The project selects a P1S with a 0.4 mm nozzle and Generic PETG. Confirm the
actual filament profile and build plate, then slice and inspect the preview.
No G-code is embedded. Do not auto-orient the parts again.

Settings stored in the project:

- 0.16 mm layers, four walls, five top and bottom layers.
- 25% infill for rigid parts; solid infill for the pad.
- Automatic normal supports enabled for the frame and curved key.
- 3 mm outer brims for the frame and clamp caps.

The frame rests on its outer rail side. The key is finger-face down, with its pad ring and
curved arm upwards; inspect supports beneath its hinge and spring peg. Caps stand on flat end faces. The pad sits on its
flat back; the curved contact face points up. The coupon sits on its flat base.

## PETG and TPU version

[`whistle-key-P1S.3mf`](../exports/single-key/whistle-key-P1S.3mf) keeps the same
orientation, using three plates: PETG pin-fit coupon, PETG mechanism parts, and
TPU pad. The TPU pad has a 0.12 mm layer-height override and solid infill. Use
external feeding for ordinary 95A TPU and select settings for the actual filament.

## Packaging and verification

The packager reads existing oriented STL exports. It does not redesign or
rescale them. The 3MF is read back with lib3mf and checked for mesh integrity,
quantities, material assignments, bed height, unaltered orientation and spacing.
The package was not opened or sliced in Bambu Studio in this environment: its
GUI executable could not run because required system libraries were unavailable.
The slicer preview remains the final check for support placement and settings.

Regenerate from the repository root:

```sh
python scripts/package_3mf.py
python scripts/package_3mf.py --dry-run --output exports/single-key/whistle-key-P1S-dry-fit-PETG.3mf
```

CI packages both versions from freshly regenerated meshes and tests their
contents. JSON files alongside the projects record part/plate assignments and
bounding boxes. Bambu project metadata follows the application's
[3MF importer](https://github.com/bambulab/BambuStudio/blob/v02.08.02.61/src/libslic3r/Format/bbs_3mf.cpp)
and plate layout conventions.

The lowered clamp-joint revision requires the new frame and both new caps. The key, pad and pin are reusable.

The subsequent full-width pillar reinforcement changes only the frame; reuse the lowered-joint caps and the existing key and pad.

The joined clamp base and enlarged spring peg revision requires a new frame and key. Reuse the current caps and pad; trial the larger peg in the actual spring.

The rounded arm-shoulder revision changes only the key. Reuse the joined-base frame and current caps and pad.

The next friction-fit trial uses 1.1 mm fixed hinge bores with the existing 1.0 × 12 mm steel pin. The moving key bore remains 1.25 mm. This supersedes the 1.0 mm frame bore for the next print; retention is not yet confirmed. Only the frame changes.

The joined-pillar pedestal revision changes only the frame, retaining the 1.1 mm fixed-bores trial. Reuse the current key, caps and pad.

The bare-brass fit and finger-clearance revision requires a new frame and both caps. Fit without a liner. Reuse the key, pin, spring and TPU pad; verify grip before playing.

For the three-hole extension, use the separate [three-key printing and assembly instructions](three-key-prototype.md) and files under `exports/three-key/`.

The three-key frame now has an opposite-side rail and a third clamp between keys 5 and 6. Print its frame flat on the base as supplied, and print three identical caps. It uses six M2 bolts/nuts. The updated projects include all eleven pieces.

The M2 nut-pocket revision changes only the three-key frame. Fit six nuts from underneath after clearing any pocket supports; hex pockets resist rotation while tightening. Current defaults are 4 mm across-flats nuts, 1.6 mm thick. Existing caps, keys and pads remain usable.

As of 2026-09-09, all three numbered keys have identical geometry, and all three
numbered pads have identical geometry (12.30 mm pad OD / 14.20 mm head OD).
Print three copies of either key file and three copies of either pad file, or use
the updated three-key 3MF. Existing frame, caps, pins and springs are reusable.

The latest pad/retaining-ring revision adds two locating tabs and matching
notches to every key. Pad body OD remains 12.30 mm; overall tab-to-tab length
is 13.80 mm. Print the pad flat backing and tabs together on the bed. Align the
tabs, seat the backing against the cup roof and glue. Reprint keys and pads
for this revision; the frame and hardware are reusable.

Clamp-cap correction (2026-09-09): use the latest caps with their complete
flat C-shaped ends on the bed. The previous 6 mm tabs held the 4 mm band 1 mm
above the bed. One end of the tabs is now trimmed flush, giving 5 mm tab width;
bolt positions and curved-band position are unchanged. Supports remain off for
caps; the 2.4 mm horizontal bolt bores use short bridges. Reprint three caps only.

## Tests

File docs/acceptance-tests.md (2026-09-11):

# Engineering and usability acceptance tests

These requirements distinguish CAD checks from evidence obtained with an actual
print and the player's whistle. Numerical margins below are provisional
engineering targets for this prototype, not clinically established values.

## Automated engineering checks

| ID | Requirement | Evidence / pass criterion |
|---|---|---|
| E01 | The mechanism reaches the opening stop and nominal pad-defined closure without unintended collision. | At 21 equally spaced positions, the key (with its integral pad face) and the EVA liner clear frame and tube. Intersection volume below 0.00001 mm³. Intended pad/brass compression is excluded. Sampling is not a continuous sweep proof. |
| E02 | The clamp body does not occupy the brass tube or its other half. | Nominal frame/cap/tube intersections below 0.00001 mm³. Actual lining compression and grip are physical tests. |
| E03 | The spring returns the key and is not driven solid. | Open spacing less than 5 mm free length; nominal closed spacing greater than assumed 2 mm solid plus 0.5 mm margin. This establishes nominal preload/travel, not return force or the maximum compression of the EVA under finger load. |
| E04 | The pin spans both supports and does not bind the moving key geometrically. | At least 0.5 mm pin projection at each end; no pin/key solid intersection and positive nominal bore clearance. Printed friction/running fits are physical tests. |
| E05 | Parts can be exported as printable closed solids. | One valid positive-volume solid per part; flat bed-contact area over 10 mm²; STEP round-trip volume within 0.0001%; watertight, consistently wound STL with volume within 1%. These checks do not prove slicability or adhesion. |
| E06 | The open pad/key do not occupy the immediate airway above the hole. | The hole's vertical projected opening stays clear through 1 mm above the tube crown. This is a geometric proxy; it does not guarantee unchanged tone or tuning. |
| E07 | The closed pad offers a continuous nominal sealing band around the hole. | Probe three concentric paths, 1.5–2.0 mm beyond the hole radius, at 5° intervals and 0.1 mm radial interference. Each point must lie within pad material. This does not establish real airtightness. |
| E08 | The pad has a continuous solid backing and one clean glue face. | At least 2 mm of solid PETG above the dish (nominally 3.8 mm), and exactly one downward cylindrical face at the recess radius, covering the nominal pad footprint. No through-hole above the whistle opening. |

These checks operate on regenerated geometry, not on hard-coded part volumes.
For example, E01 exposed a collision between the curved pad and the original
spring seat. Narrowing and moving the seat addressed that actual obstruction. E06 also
exposed the curved lip occupying the airway at 4 mm lift. Increasing the
previous prototype lift to 6 mm cleared the specified region; that layout is superseded.
The curved-arm revision uses 20° opening and about 3.25 mm lift plus sideways movement; comfort remains
subject to the player’s comfort trial.

The measured-instrument revision also checks a 1 mm axial margin between the
lower clamp and hole 5, using the still-provisional 6 mm hole 5 diameter.

The continuous-face revision additionally probes material across the centre
of the curved contact face to prevent reintroducing the rejected central relief.
The sealing-band check still applies to the outer region of this full face.

The retaining ring is superseded: the pad face is integral with the key and
the EVA is glued to it directly, so the check is now that the glue face is a
single uninterrupted cylinder covering the nominal pad footprint.

## Physical usability and function tests

Record outcomes for the right index finger first. Use the actual playing grip,
whistle, spring and pad. Do not infer any of these passes from CAD.

| ID | Requirement | Practical test and acceptance |
|---|---|---|
| U01 | The hole stays fully open under the player's unintentionally resting finger. | Rest the finger naturally on the contact while playing notes requiring the hole open. The key remains at its open stop and produces no unwanted muffling. |
| U02 | Closing is deliberate and comfortable. | Play a familiar passage with repeated closures. The player can reliably close and release without excessive effort or unacceptable fatigue. Duration and repetition count remain to be agreed with the player. |
| U03 | Closed notes seal reliably. | Compare low notes with normal finger sealing and with the key. No leak-induced weak response or instability at comfortable pressure, including after repeated closures. |
| U04 | Open-note sound is preserved. | Compare with the attachment removed and installed, including a resting finger. No player-objectionable change in response, tone or pitch. A numerical cents tolerance has not been agreed. |
| U05 | Mounting remains secure and does not mark the instrument. | Play normally, then inspect alignment, liner, brass and remaining clamp gap. No observable slip, marking or need for excessive bolt tension. |
| U06 | Other fingers and grip remain usable. | Play passages using the two uncovered right-hand holes. Clamps and rail do not obstruct fingering or force an uncomfortable grip. |
| U07 | The mechanism remains serviceable. | After repeated operation, check pin migration, return to stop, pad attachment, spring seating and wear. Cycle count and acceptable wear limits are not yet specified. |

## Force measurements to establish later

Measure force at the actual finger contact, including initial movement and full
closure, rather than quoting spring force alone. Useful eventual criteria are:

- Opening resistance exceeds the player's resting finger load by an agreed margin.
- Closure force stays within the player's comfortable deliberate force range.
- Return overcomes friction without finger assistance.

Those loads, margins and a suitable measurement method remain unestablished.
They are deliberately not assigned arbitrary Newton thresholds in CI.

## Trial record

For each trial record date, model commit, measured whistle dimensions, printer
profile, PETG and EVA brand and condition, spring identity, pin-coupon outcome,
adhesive/liner choice, and results for U01–U07. Record failures and changes as well
as passes. Extend to three keys only after the single-key results are acceptable
to the player.

The curved-arm revision additionally checks actual stop contact at full opening
and more than 0.1 mm³ interference one degree beyond it. The earlier travel
test alone did not establish a functioning stop. A hinge-height check keeps
the pivot hardware at least 2 mm below the tube crown; it cannot prove finger
comfort. First dry fit: 1.0 mm bore accepted; post strength, opening stop and
finger access failed. These three physical checks must be repeated.

The pin-access test sweeps the full 12 mm dowel continuously from outside the
lower clamp into its seated position, checking frame, both caps, key and tube.
Outside the bearings it also checks a 0.1 mm radial alignment allowance and
4 mm diameter × 2 mm tall bolt-head envelopes. This prevents accepting a pin
that fits only after assembly but cannot be inserted. Physical manipulation
and printed support strength remain trial checks.

Bare-tube closure check: translate each clamp half inward by 0.06 mm and require seat/tube intersection, no frame/cap intersection, and at least 0.8 mm remaining nominal split gap. Key travel now checks both caps as obstacles and requires at least 1 mm key/liner distance from them at all 21 sampled positions. These address observed bottoming-out and catching; they do not establish grip force or finger comfort.

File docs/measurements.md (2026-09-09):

# Whistle measurements

Instrument: brass Burke high-D whistle. All lengths are millimetres.
Hole numbers count from the mouthpiece. Bottom means footward; top means
mouthpieceward. Absolute positions use the physical open foot as the datum.

## Current independent measurements

The player rechecked each bottom edge directly from the foot. Use these
independent positions rather than accumulating the gaps along the whistle.
Diameters below are along the whistle axis; holes 5 and 6 were specifically
remeasured in that direction after conflicting span checks.

| Hole | Bottom edge from foot | Axial diameter | Derived centre | Derived top edge |
|---|---:|---:|---:|---:|
| 3 | 100.00 | 5.80 | 102.90 | 105.80 |
| 4 | 79.15 | 5.09 | 81.695 | 84.24 |
| 5 | 62.05 | 7.80 | 65.95 | 69.85 |
| 6 | 35.30 | 7.60 | 39.10 | 42.90 |

Tube OD: 14.2 mm, cylindrical at the clamp locations. Hole 4 transverse
measurement: 5.09 mm. The earlier hole 5 diameter 6.50 and hole 6 diameter
6.37 are superseded for axial calculations; do not assume they establish
transverse diameters, or assume circular holes of 7.80 and 7.60 mm. Hole 3's
5.80 mm supplied diameter is treated as axial but was not part of the latest
hole 5/6 axial recheck. Tube wall/bore and circumferential alignment remain
provisional. Derived decimal precision is arithmetic, not measurement accuracy.

| Centre spacing | Derived value |
|---|---:|
| Hole 3–4 | 21.205 |
| Hole 4–5 | 15.745 |
| Hole 5–6 | 26.85 |

## Independent gap cross-checks

| Edge span | Calculated | Direct caliper reading | Calculated minus direct |
|---|---:|---:|---:|
| Hole 3 bottom to hole 4 top | 15.76 | 15.60 | +0.16 |
| Hole 4 bottom to hole 5 top | 9.30 | 9.22 | +0.08 |
| Hole 5 bottom to hole 6 top | 19.15 | 19.20 | -0.05 |
| Hole 4 bottom to hole 6 top | 36.25 | 36.30 | -0.05 |

The corrected axial diameters resolve the large discrepancies for holes 4–6:
all three span checks now agree within 0.08 mm. These checks establish
consistency, not absolute accuracy. Keep the independently measured bottom
edges as the datum; do not average or adjust them to fit the direct gaps.

## Superseded readings

Hole 3 bottom 98.7 was corrected to 100.00; hole 4's dictated 79.23 was
corrected to 79.15; hole 5 bottom 60.87 was corrected to 62.05; hole 6 bottom
34.1 was corrected to 35.30. Hole 5 axial diameter 6.50 was corrected to 7.80;
hole 6 axial diameter 6.37 was corrected to 7.60. The earlier hole 4 centre
81.68 was an approximate centre reading. Historical gap-chain reconstructions
are not adopted; prior calculations remain available in repository history.

## Prototype status and pending geometry

The three-key source `scripts/three_key.py` and its exports now use this
reconciled measurement set. The earlier single-key source is retained unchanged.
The player previously requested a cap-only revision to retain the printed
single-key frame; the subsequent three-hole extension uses a new longer frame.
The existing printed frame uses clamp offsets +13 and -9 from hole 4.
Neighbouring-hole clearances must use the reconciled positions above.

No liner was installed. Clamp faces met without gripping adequately. The
spring and hinge were assembled and operated, and the TPU pad made a
reasonable seal. Finger interference and key catching remain P1 issues.
M2 nut pockets have now been added to the three-key frame, using unconfirmed standard 4 mm across-flats × 1.6 mm nut dimensions.

The latest pin-fit trial uses 1.1 mm fixed bores for a 1.0 × 12 mm steel pin;
the moving bore is 1.25 mm. All three pads now use a 12.30 mm diameter with
a continuous concave contact face, sized for the largest hole (7.80 mm).

On 2026-09-09 the player confirmed the recorded hole measurements as correct.
The independent bottom edges and diameters above are retained without adjustment.
All three keys and pads are now interchangeable, as requested; there are no engravings.
No separate new transverse readings were supplied; the existing circular clearance
envelopes remain the design assumption.

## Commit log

2026-09-06 Add single-key whistle prototype, design brief and CAD CI tests
    [assembly-open.step, clamp_cap_0.step, clamp_cap_0.stl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]
2026-09-07 Fit single-key prototype to measured Burke whistle dimensions
    [assembly-open.step, clamp_cap_0.step, clamp_cap_0.stl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]
2026-09-07 Use a continuous concave TPU pad contact face
    [assembly-open.step, tpu_pad.step, tpu_pad.stl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]
2026-09-07 Remove rigid closing stop; let TPU pad set closure
    [assembly-open.step, frame.step, frame.stl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]
2026-09-07 Seat the TPU pad in a shallow glue-in retaining ring
    [assembly-open.step, lever_blank.step, lever_blank.stl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]
2026-09-07 Locate spring with lower socket and tapered upper peg
    [assembly-open.step, frame.step, frame.stl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]
2026-09-07 Package oriented P1S print projects including all-PETG dry fit
    [whistle-key-P1S-dry-fit-PETG.3mf, whistle-key-P1S.3mf]
2026-09-08 Curve key around whistle with low reinforced hinge and positive opening stop
    [assembly-open.step, clamp_cap_0.step, clamp_cap_0.stl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]
2026-09-08 Lower clamp joint and rail to clear hinge pin insertion
    [assembly-open.step, clamp_cap_0.step, clamp_cap_0.stl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]
2026-09-08 Broaden hinge pillars into full rail-width buttresses
    [assembly-open.step, frame.step, frame.stl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]
2026-09-08 Join lower clamp arcs to solid bases and enlarge spring peg
    [assembly-open.step, frame.step, frame.stl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]
2026-09-08 Fill key arm inside shoulder with tangent radius
    [assembly-open.step, lever_blank.step, lever_blank.stl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]
2026-09-08 Trial 1.1 mm fixed hinge bores for steel pin fit
    [assembly-open.step, frame.step, frame.stl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]
2026-09-08 Fill lower gaps between hinge pillars and spring seat
    [assembly-open.step, frame.step, frame.stl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]
2026-09-08 Size clamps for bare whistle and increase playing clearances
    [assembly-open.step, clamp_cap_0.step, clamp_cap_0.stl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]
2026-09-08 Record measured hole three diameter and position
2026-09-08 Record corrected hole five size and position
2026-09-08 Record measured hole six diameter and position
2026-09-08 Reconcile hole positions from rechecked edge gaps
2026-09-08 Use independent foot-to-hole measurements as reference
2026-09-08 Correct hole three bottom edge to 100 mm
2026-09-08 Record corrected independent hole four and five positions
2026-09-08 Complete independent hole measurements with hole six correction
2026-09-08 Record direct hole four to six span cross-check
2026-09-08 Correct hole six axial diameter and reconcile span checks
2026-09-08 Reconcile hole four to six geometry with axial diameters
2026-09-08 Extend working Burke key mechanism to measured holes four five and six
    [assembly-open.step, clamp_cap_print.step, clamp_cap_print.stl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]
2026-09-08 Close frame with return rail and add middle clamp
    [assembly-open.step, frame_print.step, frame_print.stl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]
2026-09-08 Add reinforced underside M2 nut pockets to three-key frame
    [assembly-open.step, frame_print.step, frame_print.stl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]
2026-09-08 Add Draftwright titanium frame machining review drawings
    [frame-features.dxf, frame-general.dxf, frame-reference.step]
2026-09-09 Standardize all three keys and pads on the largest hole size
    [assembly-open.step, lever4_print.step, lever4_print.stl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]
2026-09-09 Locate common TPU pads with opposed tabs and ring notches
    [assembly-open.step, lever4_print.step, lever4_print.stl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]
2026-09-09 Start clamp cap bands on bed by trimming recessed tab ends
    [assembly-open.step, clamp_cap_print.step, clamp_cap_print.stl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]
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2026-09-09 Reinforce fixed hinge bearings and add pin insertion lead-ins
    [assembly-open.step, frame_print.step, frame_print.stl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]
2026-09-09 Join spring uprights to both hinge pillars with reinforcing webs
    [assembly-open.step, frame_print.step, frame_print.stl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]
2026-09-09 Make spring holder backs flush and brace socket undersides
    [assembly-open.step, frame_print.step, frame_print.stl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]
2026-09-09 Reinforce curved key arms after reported print fractures
    [assembly-open.step, lever4_print.step, lever4_print.stl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]
2026-09-09 Reinforce key hinge bores with collars and matching spring clearance
    [assembly-open.step, frame_print.step, frame_print.stl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]
2026-09-09 Fill unused rear key notch with continuous tangent web
    [assembly-open.step, lever4_print.step, lever4_print.stl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]
2026-09-10 Increase key opening to 35 degrees and prototype EVA liners with cutting guide
    [assembly-open.step, clamp_cap_print.step, clamp_cap_print.stl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]
2026-09-10 Restore original TPU pad outline and resize EVA cutting guide
    [assembly-open.step, eva-cutting-template.3mf, eva_cutting_template.step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]
2026-09-11 Glue 2 mm EVA directly to an integral key pad face
    The keys carried a separate 95A TPU pad in a retaining ring. Recessing that
    carrier for the user's 2 mm EVA sheet left only a 0.8 mm TPU shell behind the
    foam and narrowed the sealing footprint, because a thicker liner in a 12.3 mm
    carrier wraps less of the tube.
    Merge the pad into the key instead. Each key now has a dished boss printed as
    part of it, cut by a cylinder of 8.9 mm radius concentric with the whistle at
    closure (7.1 tube radius, less 0.2 interference, plus the 2.0 sheet). The EVA
    is glued straight into it.
    - The glue surface is one continuous cylindrical face of 175.69 mm2, with no
    ring, tab notch, step or parting line on it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
    [assembly-closed.step, assembly-open.step, clamp_cap_print.step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]
2026-09-11 Package the three-key print as one all-PETG plate
    Every three-key part is PETG now that the pad is integral with the key, so the
    separate coupon plate and the all-PETG dry-fit duplicate served no purpose.
    Put frame, three keys, three clamp caps, cutting guide and pin coupon on a
    single plate in whistle-three-key-P1S.3mf, drop the dry-fit three-key export
    and its CI step, and limit --dry-run to the single-key model, where it still
    substitutes PETG for the TPU pad.
    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
    [whistle-three-key-P1S-dry-fit-PETG.3mf, whistle-three-key-P1S.3mf]
2026-09-11 Add 3 mm spring variants of the three-key mechanism
    scripts/three_key.py gains a spring table and builds three variants from one
    source; build_ci.py --model selects them. Run on its own the file still builds
    the 2 mm mechanism unchanged.
    The coil axis passes over the pivot, so clearance to the reinforced hinge collar
    is the perpendicular distance from pivot to axis, less the collar radius and the
    coil radius, and the worst case is at full opening where the coil is most
    tilted. A 3 mm coil takes 0.5 mm more than a 2 mm one and fouls the collar at
    35 degrees, so the seat must rise, which lengthens the swing and spends preload.
    - three_key_3mm_spring: 3.0 x 6.0, 35 degrees, seat 3.70. Collar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
    [assembly-closed.step, assembly-open.step, clamp_cap_print.step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]
2026-09-11 Let the foam, not the frame, stop the key at closure
    The player trial reported pads that do not seal reliably enough to play.
    Nothing hard-stops the key at closure by design, so finger force should compress
    the foam. It did not: the key landed on the top rear corner of the spring holder
    1.22 degrees past nominal closure, capping compression at 0.44 mm, 22% of the
    2 mm liner, however hard it was pressed. 0.1 mm of PETG oversize there takes it
    back to the 0.2 mm design figure. Foam needs roughly 25-40% compression to
    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
    [assembly-closed.step, assembly-open.step, clamp_cap_print.step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]
2026-09-12 Shape the key tops for the finger
    Overnight seating fixed the seals, so the keys are now shaped rather than
    sized. The pad boss ran out to the arm's own crown, leaving a flat-topped drum
    standing proud of the arm: 725 mm3 of PETG above the recess, 77% of the key,
    and 7.33 mm thick at the pad rim against 3.80 at its centre.
    Drop the finger face to a flat plane 11.0 mm from the tube axis, 3.9 mm above
    the whistle, with a 1.5 mm chamfered rim. The plane is close to tangent to the
    arm's curve so the arm rises into the face instead of stepping against it. A
    cylindrical dome was tried first and rejected: it sits below the arm everywhere
    over the pad and leaves a thin fin standing up beside the fi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
    [assembly-closed.step, assembly-open.step, clamp_cap_print.step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]
2026-09-12 Relieve the finger face's own edge, not the pad circle
    The rim chamfer cut a trench across the finger face. The arm reaches the face
    at full height, so chamfering the pad circle bevelled a ring that the arm sits
    inside: along y = 0 the surface ran 11.00 on the arm, dropped to 9.60, then
    climbed back to 11.00 on the pad, a 1.4 mm channel right where the finger
    lands.
    Chamfer the boundary of the flat face itself instead. That boundary is the free
    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
    [assembly-closed.step, assembly-open.step, clamp_cap_print.step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]
2026-09-12 Crown the key top with a cylinder instead of a flat face
    Replace the flat finger face, its rim chamfer and the faceted reinforcement
    crown with a single cut: a cylinder of 25 mm radius about the tube axis,
    truncated by a 0.2 mm flat landing at the apex. One smooth surface now runs
    from the arm over the pad, so the angular shoulder above the arm reinforcement
    is gone along with the chamfer crease.
    The crown has to be cylindrical rather than spherical. The EVA recess is a
    cylinder about the same axis and does not vary along the whistle; a spherical
    crown does, and closes on the recess at the pad's axial edges, leaving 1.30 mm
    of PETG there against the 2.10 mm a cylindrical crown holds everywh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
    [assembly-closed.step, assembly-open.step, clamp_cap_print.step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]
2026-09-12 Reduce the opening from 35 to 27 degrees
    The player measured about 6 mm of gap above an open hole and asked for 2 mm
    less. The figure quoted in earlier notes, 4.042 mm, is the minimum three
    dimensional distance from liner to tube, which occurs off to the side at the
    pad's trailing edge. Straight up over the hole, where it is actually measured,
    35 degrees gives 5.94 mm. The model and the instrument agreed all along; only
    the quantity being quoted was wrong, and an angle picked against it would have
    been far too small.
    27 degrees brings that to 4.78 mm, 1.16 mm of the 2 mm asked. A full 2 mm needs
    22 degrees, which drops minimum three dimensional clearance to 2.48 mm and
    breaks the 3 mm rule;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
    [assembly-closed.step, assembly-open.step, clamp_cap_print.step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]
2026-09-12 Restore the arm section that fractured a key
    A key fractured before being played, on the outside of the curve level with the
    spring housing. The cause was my closure over-travel fix: the spring-housing
    relief went from 0.3 to 0.8 mm in both x and z, and the x component cut the arm
    from the inside exactly where bending stress peaks. Section modulus at the 65
    degree station fell 4.86 to 2.77 and peak stress rose 2.09 to 3.66, a 75%
    increase. The two probes guarding the bend sit at 55 and 70 degrees, either
    side of the damage, so the suite stayed green.
    Split the relief: 0.3 mm in x as before, 0.8 mm in z. The over-travel comes
    almost entirely from the z component, so this keeps 3.58 degrees p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
    [assembly-closed.step, assembly-open.step, clamp_cap_print.step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]
2026-09-12 Round the notch staircase at the fracture station
    Restoring the arm section was not the whole story. A section through the arm at
    the fracture station showed a staircase of sharp inside corners where the spring
    clearance channel meets the housing relief and where the peg leaves the arm:
    nine line-to-line corners between x -13 and -8. Station 65 degrees, where the
    key broke, sits at (-10.11, 4.72), directly on that staircase. A sharp
    re-entrant corner concentrates stress whatever the section area is, and on a
    printed part it also falls between extrusion paths.
    Round three of them: the channel top where it meets the relief face (0.6 mm),
    the channel's far end (0.5 mm) and the peg root (0.6 mm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
    [assembly-closed.step, assembly-open.step, clamp_cap_print.step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]
2026-09-13 Remove a sharp tail notch introduced by the fracture fix
    Raising upper_arm_radial_extra 1.0 -> 1.8 to restore the arm section also
    raised reinforced_r 13.7 -> 14.5. The back web is built tangent to the arm at
    that radius, so the tangent point dropped from z 6.396 to 4.221 - below
    arm_reinforcement_full_z of 6.0. The web then met the arm while the arm was
    still ramping up to full radius, so the surfaces crossed instead of touching
    and left a 48.9 degree sharp re-entrant V at (-12.951, 4.221). The opening stop
    spans x -13.7 to -12.2, putting the notch in the middle of the impact zone.
    The tail was a single 5.54 mm line before the change and four segments after.
    Found in a draftwright drawing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
    [assembly-closed.step, assembly-open.step, clamp_cap_print.step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]
